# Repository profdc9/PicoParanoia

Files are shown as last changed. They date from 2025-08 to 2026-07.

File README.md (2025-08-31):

# PicoParanoia

This is an update to the ParanoiaBox ( https://www.github.com/profdc9/ParanoiaBox ) which uses a Raspberry Pi Pico rather than a STM32F103CBT6 Blue Pill.  It improves some security aspects of the original, such as having separate SPI ports for the ciphertext and plaintext cards.

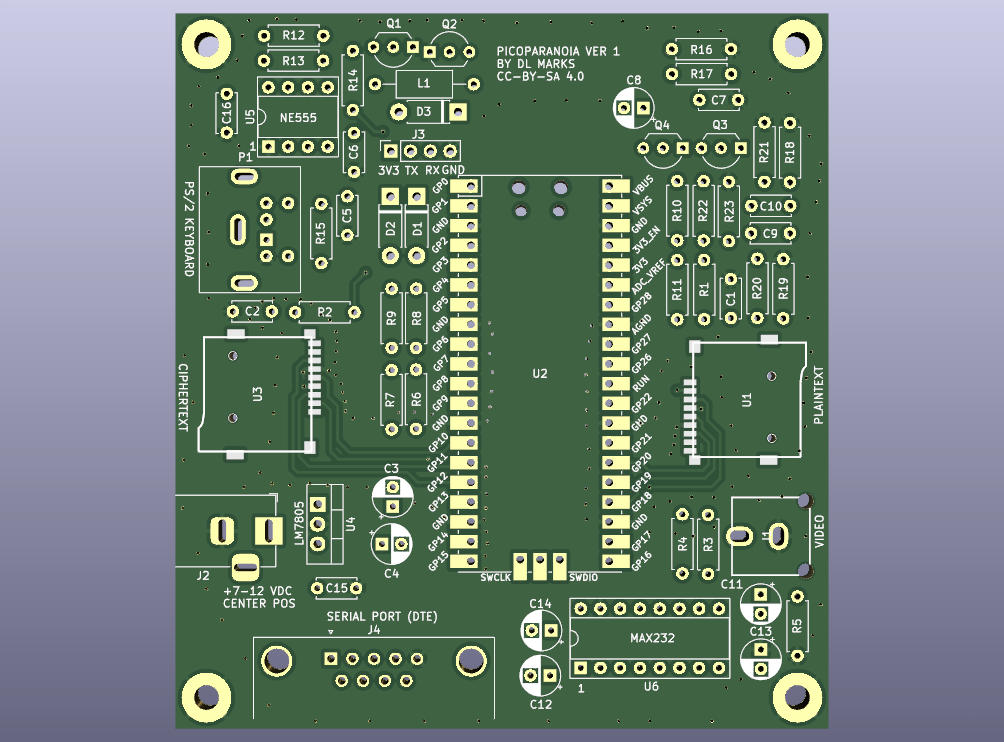
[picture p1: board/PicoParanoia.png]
PCB


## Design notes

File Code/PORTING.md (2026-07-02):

# PicoParanoia — Porting Plan (STM32 ParanoiaBox → RP2040 Pico)

Status: **bring-up step 1 complete** (copy-to-RAM skeleton + vendored crypto
subset building; AES-256-GCM/BLAKE2s self-test ready to flash). Steps 2+ pending.

Porting the ParanoiaBox encryption terminal (`~/projects/ParanoiaBox/code`,
STM32F103CBT6 / stm32duino) to the Raspberry Pi Pico (RP2040), built on the
Pico SDK (vendored at `../pico-sdk`, v2.2.0).

Decision: keep the **Arduino Cryptography Library** (Rhys Weatherley). It is
pure software except for the RNG noise source, which we wire to the RP2040 ADC.

---

## 0. Design principles

This is an encryption device; its credibility rests on the firmware being
**auditable**. Two standing rules shape every decision in this document.

### A. Auditability first

- **Minimize the trusted computing base.** Every dependency is audit surface.
  Vendor and pin all third-party code (Pico SDK, Crypto lib, TinyUSB, FatFs)
  with recorded version + license + provenance; add nothing we can't justify.
- **Isolate the security-critical core** — crypto primitives, key management,
  RNG/entropy, flash key store, and the plaintext/ciphertext data path — into
  small, dependency-light modules reviewable on their own, separate from
  UI / video / USB / SD.
- **Document the trust boundary.** Be explicit about what touches secrets:
  keys & passphrases (`keymanager`, KDF), plaintext (`editor`, plaintext SD
  card, the video display, **and keyboard input — it carries the passphrase**).
  Non-secret: ciphertext, video sync/timing, the NTSC engine internals.
- **Zeroize secrets after use** — wipe key material, derived keys, passphrases,
  and plaintext buffers when done. The STM32 code is inconsistent here; the port
  is the chance to make this systematic.
- **Readable over clever.** Clear names, comments on *why*, modest functions, no
  undefined behavior; match the existing zlib-licensed style.
- **No hidden behavior.** Offline by design — no network, telemetry, or
  auto-update; no code path that isn't on the menu.
- **Constant-time where it matters.** Tag/secret comparisons go through the
  audited Crypto lib; flag any hand-written comparison over secret data.
- **Reproducible builds.** Pinned SDK submodule + toolchain + `copy_to_ram` so an
  auditor can rebuild the exact image and diff it. Document the build.

### B. Reusable, decoupled libraries

- The **NTSC/PAL video driver is a standalone, reusable library** — its own
  directory, its own CMake static-library target, a clean public header, and
  **zero dependency on PicoParanoia** (no `keymanager`/`consoleio`/etc.). It
  knows only about a framebuffer + timing config, so it drops into other
  projects unchanged.
- This *also serves auditability* (principle A): it lifts a large,
  non-security-critical component out of the crypto core's review surface.
- The `consoleio` shim sits **on top of** the video library, bridging it (and
  the keyboard) to the app — app-specific behavior stays out of the library.

---

## 1. Hardware differences (STM32 Blue Pill → RP2040 Pico)

### 1.1 Pin map (RP2040, confirmed 2026-06-30)

| Function | RP2040 GPIO | Notes |
|---|---|---|
| PS/2 DATA | GPIO4 | was `PB4` |
| PS/2 CLK | GPIO5 | was `PB5` |
| Ciphertext SD — SCK | GPIO10 | HW peripheral **spi1** |
| Ciphertext SD — MOSI | GPIO11 | |
| Ciphertext SD — MISO | GPIO12 | |
| Ciphertext SD — CS | GPIO13 | was shared bus + `PB8` CS |
| Plaintext SD — SCK | GPIO18 | HW peripheral **spi0** |
| Plaintext SD — MOSI | GPIO19 | |
| Plaintext SD — MISO | GPIO20 | |
| Plaintext SD — CS | GPIO21 | was shared bus + `PB9` CS |
| Video VSYNC | GPIO16 | NTSC/PAL |
| Video pixel clock | GPIO17 | NTSC/PAL |
| Noise transistor A | GPIO26 | ADC channel 0 |
| Noise transistor B | GPIO27 | ADC channel 1 |
| UART TX | GPIO0 | HW peripheral **uart0** |
| UART RX | GPIO1 | |
| UART CTS | GPIO2 | hardware flow control |
| UART RTS | GPIO3 | hardware flow control |

Exposed serial port (UART) — **not needed for the initial port, recorded for
later use.** GPIO0/1 are the RP2040 `uart0` function pins, with CTS/RTS flow
control on GPIO2/3.

### 1.2 Two SD cards on independent SPI buses (security-critical)

The STM32 version put **both** SD cards on a single SPI bus, distinguished
only by chip-select lines (`PB8` ciphertext, `PB9` plaintext). The Pico
version deliberately puts each card on its **own SPI controller** so that
neither card can electrically observe the other's traffic — preserving the
plaintext/ciphertext air-gap that is the whole point of the device.

- Ciphertext card → RP2040 **spi1** (GPIO10–13)
- Plaintext card → RP2040 **spi0** (GPIO18–21)

**Naming gotcha:** the schematic labels these nets "SPI2" (ciphertext) and
"SPI1" (plaintext), which are *off by one* from the RP2040 peripheral names
(`spi1` and `spi0` respectively). Code and comments must state which numbering
is meant. The FatFs disk-IO glue needs two independent SPI contexts, one bound
to each controller — not one bus with two CS lines.

### 1.3 Hardware RNG: dual simultaneous ADC → single muxed ADC

STM32 `random.cpp` drove `ADC1` and `ADC2` **simultaneously** (register-level
`SQR3`/`CR2`/`SR`/`DR` pokes) to sample two noise transistors at once. The
RP2040 has a **single** ADC multiplexed across channels. The two transistors
on ADC0 (GPIO26) and ADC1 (GPIO27) must be sampled in sequence (switch the
input mux between conversions, or use round-robin mode) and combined. The
output then feeds the Arduino Crypto library's `RNG` whitening.

#### 1.3.1 Low noise amplitude → only the lowest LSBs are random (critical)

The noise source is a **reverse-biased emitter–base junction**, and its noise
amplitude is only **~100 mV**. Against the RP2040's 12-bit ADC over a 3.3 V
reference (**~0.8 mV/LSB**), 100 mV spans only ~125 codes — and the *random*
content lives in just the **lowest few LSBs** of each sample. The upper bits
track the DC bias and slow drift, not entropy. So a raw ADC sample carries far
less real entropy than its bit-width suggests.

**Design mandate (do not skimp on entropy):**

- **Credit conservatively.** Assume only a small handful of bits — treat it as
  **≤1–2 bits of true min-entropy per ADC sample** (or less), never the full
  8/12 bits. Tell the `RNG`/`NoiseSource` credit accounting this low number.
- **Oversample *very* generously.** Gather many times more raw samples than the
  output needs and fold them all through the BLAKE2s/ChaCha whitening pool. For
  any key, nonce, IV, salt, or ECDH scalar, target a large safety margin
  (**≫10×** the credited bits required) so the noise source is **never** the
  limiting factor. When in doubt, gather more.
- **Block until satisfied.** Before generating key material, force a generous
  entropy stir-in and wait until the pool has absorbed well beyond the nominal
  requirement — never produce a key/nonce from a thin pool.
- **Debias / combine.** Prefer the low bits; consider von Neumann debiasing and
  XOR-combining the two independent channels (GPIO26/GPIO27) before crediting.
- **Health check.** Implement a real stuck-source detector (the STM32
  `random_circuit_check()` was an empty stub): if the LSBs go constant the
  junction/biasing has failed, and oversampling a dead source yields nothing —
  fail loudly rather than emit predictable keys.

This is a security-critical, auditable property (§0.A): generosity here is
deliberate and must be obvious in the code and its comments.

#### 1.3.2 RNG construction: direct BLAKE2s extraction (decided)

The conditioner is a **direct hash extractor**: sample the noise generously,
fold it through **BLAKE2s**, and take the digest as the random output — no
long-lived DRBG state. Chosen over an extract-then-DRBG hybrid because our
random demand is small and intermittent (keys, nonces, IVs, salts, ECDH
scalars), and a stateless "hash a big pile of fresh noise" construction is the
easiest thing for an auditor to trust (§0.A).

- **Memory cost is negligible — no need to buffer the oversampled noise.**
  BLAKE2s is incremental, so samples are `update()`-ed into the hash state as
  they're collected and immediately discarded. The only standing memory is the
  BLAKE2s context (~100–200 B) plus a tiny per-sample working buffer — *not* the
  thousands of raw samples. (Even copy-to-RAM's 264 KB would swallow a multi-KB
  buffer easily; we simply don't need one.)
- **One 256-bit extraction covers every secret we generate.** BLAKE2s' 32-byte
  digest ≥ AES-256 key, ECDH25519 scalar, and any nonce/IV. If something ever
  needs >256 bits, run **independent** extractions over fresh noise (or a keyed
  counter expansion), never stretch one digest.
- **Per call:** reset BLAKE2s → stream in ≫(output bits) of credited noise
  (debiased, two channels XOR-combined, §1.3.1), running the stuck-source check
  as samples arrive → `finalize()` → output. Block until the credited input
  margin is met.
- Reminder: extraction makes a **dead source look random** (§1.3.1), so the
  health check during sampling is what actually guarantees the result, not the
  hash.

### 1.4 Internal flash key storage: STM32 flash controller → RP2040 QSPI

STM32 `flashstruct.cpp` programmed the on-die flash via `FLASH_BASE->KEYR`
unlock + page erase, and `keymanager.h` hardcodes `0x0801E000` (STM32 memory
map). The RP2040 has **no internal flash** — code/data live in external QSPI
flash. Key storage must move to the SDK's `hardware/flash.h`
(`flash_range_erase` / `flash_range_program`, 4 KB sectors). The hardcoded
address and the 16-bit half-word write granularity assumptions go away.

Interaction with copy-to-RAM (§1.9): because the firmware runs entirely from
RAM, the usual "flash writes must execute from RAM with IRQs off" hazard is
largely handled by construction — no code is being fetched from the flash we're
erasing. Reserve a dedicated key region at the **top of flash** (outside the
copied program image) for the encrypted key store. Reading keys back is an
XIP-mapped read of that region; that traffic is acceptable because only
**ciphertext** key blobs ever cross the bus (see §1.9).

### 1.5 NTSC/PAL video generation

STM32 used the `TNTSChar` library, which generated composite video by abusing
an SPI peripheral + timers (libmaple). On RP2040 both SPI controllers are spoken
for by the SD cards, so composite video is generated with **PIO + DMA**.
Architecture settled 2026-06-30; this is the largest single new component, but
fully specified below.

**Output DAC — 2-resistor summing into 75 Ω composite.**
GPIO16 (sync) via **560 Ω** and GPIO17 (luma) via **240 Ω** sum into the 75 Ω-
terminated TV input. Measured/computed levels:

| State | GPIO16 | GPIO17 | Composite |
|---|---|---|---|
| Sync tip | 0 V | 0 V | 0 V |
| Black/blanking | 3.3 V | 0 V | ≈0.31 V |
| White | 3.3 V | 3.3 V | ≈1.02 V |

Standard 0 / 0.3 / 1.0 V composite. **Monochrome** — no colorburst, so the pixel
clock is free of the 3.579545 MHz subcarrier constraint.

**Display model.**
- **Text cells only**, 240p **progressive** (non-interlaced, one field repeated).
  NTSC first; PAL later = different line/field counts + sync templates, same
  machinery (keep all timing in one table).
- **25 rows × 8 px = 200 active lines**, identical in both column modes — so the
  GPIO16 sync waveform is **mode-independent in real time**.
- **40-column (320 active px) and 80-column (640 active px)** both supported,
  switchable like `TNTSChar`.
- **1bpp framebuffer** rendered from a font ROM. Glyphs are drawn into the
  framebuffer **only on text change** (in `console_putch`/scroll), never per
  scanline. Sizes: 40-col 8 KB, 80-col 16 KB (×2 if double-buffered) — trivial
  under copy-to-RAM (§1.8).

**PIO scanout engine.**
- **Two SMs in one PIO block sharing one `clkdiv`**, started together
  (`pio_enable_sm_mask_in_sync`): one drives GPIO16 (sync), one drives GPIO17
  (luma), bit-aligned.
- SMs run **free-running for the whole field**; DMA is **ping-pong/chained** so
  the FIFOs never underrun. (Underrun = loss of lockstep = torn sync — this is
  *the* failure mode to design out, hence no per-line SM restarts.) The per-line
  IRQ only swaps buffer pointers.
- The **sync SM** streams a small set of precomputed line templates selected per
  line by a DMA descriptor list: normal-active, blank, pre-equalizing,
  broad/serration, post-equalizing (NTSC field structure).
- The **luma SM** streams a shared "black" buffer around the active framebuffer
  row each line, so porch/blanking is handled by DMA sequencing and the
  framebuffer stays pure picture (no per-line copy).

**40 vs 80 columns.** Keep the PIO clock **fixed at the 80-col pixel rate**
(~12.2 MHz); 80-col = 1 framebuffer bit/clock, 40-col = each bit held 2 clocks
(double-width pixels). Sync templates and clock are untouched between modes —
only the luma SM packing + framebuffer geometry change. (Alternative: halve the
shared `clkdiv` + mode-specific sync templates. Either way a mode switch
re-inits the engine at a field boundary, which is rare.)

**Pixel clock.** 80-col: 640 px / ~52.6 µs ≈ **12.2 MHz**; 40-col ≈ 6.1 MHz.
Choose sysclk + active-pixel count for an integer / low-jitter PIO divider
(monochrome gives freedom here).

**Scrolling.** A text scroll moves pixels, not just chars, but the cost is
negligible — an 80-col scroll `memmove`s ~15 KB (framebuffer minus one char
row), << one line time. Do it during **vertical blanking** (~3.9 ms available)
to avoid tearing, or render to the back framebuffer and swap. Zero-copy upgrade
if ever needed: a per-line pointer table (ring framebuffer) so a scroll rotates
pointers instead of moving pixels.

**Core split.** *(Updated after first light — superseded for the chosen
single-SM path.)* With the single-SM + precomputed static-frame design, scanout
is pure DMA + PIO with **no per-scanline CPU**, so there is **no video engine
loop and core1 is unused**. Glyph blitting happens on **core0** at text-change
time (blit-on-write), not per line. **core1 is free** — most likely future
tenant is the TinyUSB **host** service loop (deferred, off by default); it can
also absorb an offloaded task if core0 ever gets busy. The original "video on
core1" note applied to the two-SM/per-line-composition model, which we did not
take.

Remaining choices are implementation-level only: exact sysclk/divider, the
scroll-tearing mitigation (vblank memmove vs double-buffer), and the 40-col
mechanism (double-width vs `clkdiv` change).

### 1.6 Keyboard input — PS/2 *or* USB host (new requirement)

The Pico version must accept **either a PS/2 keyboard or a USB keyboard**, a
capability the STM32 version did not have.

- **PS/2:** was the `PS2Keyboard` lib bit-banging `PB4`/`PB5`; same protocol,
  new pins (GPIO4 data, GPIO5 clk). RP2040 PIO program or IRQ bit-bang. Low risk.
- **USB host:** the RP2040 acts as a **USB host** and reads a USB HID boot
  keyboard via TinyUSB host mode. Both sources feed a single key event queue
  that `consoleio` drains, so the rest of the system is source-agnostic.

### 1.7 USB role: device (debug) → host (keyboard) — and what it costs stdio

The RP2040 has **one native USB controller**, which is *either* device *or*
host — not both at once on that port. This drives a deliberate two-phase plan:

- **Bring-up phase:** native USB in **device** mode = USB-CDC serial, used as
  the debug `stdio` console (printf, crypto self-tests, etc.).
- **Target phase:** native USB switches to **host** mode to drive the USB
  keyboard. At that point **USB-CDC stdio is gone** — any persistent debug
  console must move to **`uart0` (GPIO0/1)**, or be compiled out entirely for
  the shipping build.

Implication: treat USB-CDC stdio as **temporary scaffolding**. Keep all debug
output behind a thin logging shim with a build-time backend switch
(USB-CDC ↔ `uart0` ↔ none) so flipping the USB role doesn't ripple through the
code. (A second USB port via Pico-PIO-USB — host on PIO pins while native stays
device — is a possible future option but is **not** assumed here; the board
allocates no pins for it.)

**USB is off by default (least privilege / auditability, §0.A).** Some users
will not trust the USB stack on an encryption device, so USB must be **entirely
compile-time optional and inert unless explicitly enabled**:

- `PICOPARANOIA_ENABLE_USB_HOST` (default **OFF**) — compiles out the TinyUSB
  host + HID-keyboard driver. With it off, the keyboard is PS/2-only and no USB
  code is linked at all.
- `PICOPARANOIA_ENABLE_USB_STDIO` (default **OFF**) — USB-CDC debug console is
  opt-in even during bring-up; a developer turns it on deliberately. Default
  debug target is `uart0` (or none).
- A build with both off links **no USB code**, and the native USB peripheral is
  left uninitialized/inert. Each flag is independent so "USB keyboard, no debug
  CDC" and "CDC debug, PS/2 keyboard" are both valid configs (and the two CDC vs
  host modes remain mutually exclusive per the controller limit above).

This keeps the default firmware's attack/audit surface minimal: no USB unless
the operator chose it.

### 1.8 Execution entirely from RAM (copy-to-RAM) — flash-bus hardening

**Requirement:** the whole firmware image is copied from flash into RAM at
startup and executes from **SRAM**, so that no instruction fetches go out over
the external QSPI flash lines at runtime. Default RP2040 operation is XIP
(execute-in-place), where every cache-missed fetch is visible on the flash bus;
an attacker probing those lines could infer secret-dependent control flow and
data accesses. Running from RAM removes that side channel.

- **Mechanism:** the Pico SDK provides this out of the box —
  `pico_set_binary_type(picoparanoia copy_to_ram)` selects the copy-to-RAM
  linker layout; boot stage 2 copies the image to SRAM and jumps to it. No
  custom bootloader needed.
- **RAM budget (hard constraint):** everything — code, rodata, data, bss,
  stack, heap, **plus** the text-cell video buffer, FatFs/file buffers, USB-host
  buffers, and crypto working state — must fit in the RP2040's **264 KB SRAM**.
  This firmware is small, but watch the file-encryption buffers and keep an eye
  on the map file as modules land. Treat RAM headroom as a tracked budget.
- **Flash stays available for the encrypted key store only.** After the boot
  copy, the flash is otherwise idle. The only runtime bus traffic to flash is
  reading/writing the **encrypted** key region (§1.4) — and because those blobs
  are ciphertext, observing them on the bus leaks nothing useful.
- **Boot copy is not a secret-bearing operation:** the one-time bulk copy of the
  (non-secret) program image happens before any key is decrypted, so the
  unavoidable flash traffic at boot carries no secrets.
- Algorithmic constant-time behavior (execution-*time* side channels) is a
  separate concern, handled in the crypto library, not by this RAM decision.

> Possible hardening to evaluate later: actively quiesce/disable the XIP cache
> and flash between key accesses so the bus is fully idle except during explicit
> encrypted-key reads/writes.

### 1.9 Toolchain / framework

stm32duino Arduino core → bare-metal Pico SDK (CMake, `arm-none-eabi`). No
`Arduino.h`, `Serial`, libmaple, or stm32duino `SPI`/`RNG` glue. `printf`
routes through the logging shim (§1.7). Crypto lib must be compiled as plain
C++ against the SDK rather than the Arduino build. USB stack: **TinyUSB**
(bundled with the SDK) in device mode early, host mode later. Binary type:
**copy-to-RAM** (§1.8).

---

## 2. Module port strategy

Legend: **Reuse** = compiles essentially unchanged · **Shim** = keep the
module's API/logic, swap the platform calls underneath · **Rewrite** = replace
the implementation · **New** = no STM32 counterpart.

| Module (old) | Disposition | Work |
|---|---|---|
| `mini-printf.*` | **Reuse** | Pure C string formatting. |
| `debugmsg.*` | **Shim** | Route through the logging shim (§1.7): `uart0` by default, USB-CDC only if `PICOPARANOIA_ENABLE_USB_STDIO` is set, or none. Not `Serial`. |
| `cryptotool.*` | **Reuse** | AES/GCM/BLAKE2s via Crypto lib, base64, CRC16, KDF — all software. Only `heap_stack_distance()` (uses `sbrk`/frame address) needs an SDK-friendly version or removal. |
| Crypto library | **Reuse (recompile, pinned subset)** | Vendor `libraries/Crypto/` at commit `37a76b8` (§2.3) — the GCM/AES256/CTR/BLAKE2s/Curve25519 subset, plus ChaCha/ChaChaPoly/Poly1305 added later (§2.1 step 7a) when the active AEAD cipher was swapped to ChaCha20-Poly1305; GCM/AES256 stay vendored for their KAT. Compile as plain C++ against the SDK. **Drop `RNGClass`/`NoiseSource`/Arduino glue entirely** — direct BLAKE2s extraction (§1.3.2) replaces the DRBG, so that Arduino-coupled code never enters the build (the standalone `ChaCha` class is vendored, but not `RNGClass`'s own use of it). |
| `editor.c` | **Reuse** | Talks only to the `consoleio` API; works once console is up. |
| `keymanager.*` | **Shim** | Logic is portable. Replace the flash-storage backing (see `flashstruct`) and the hardcoded `0x0801E000` address with an RP2040 QSPI region. |
| `fileenc.*` | **Reuse** | Pure logic over `keymanager` + `fileop` + `cryptotool`. |
| `fileop.*` | **Shim** | FatFs calls stay; the disk-IO layer underneath becomes two independent SPI/SD contexts (see below). `fs0`=ciphertext, `fs1`=plaintext. |
| FatFs | **Update + new glue** | Move to **R0.16** (§2.3), replacing the old STM32-glued `ElmChanFatFs`. Portable `source/` + our own `diskio.c` for the two SPI buses (`sdmm.c` sample as reference); `FF_VOLUMES = 2`. |
| `consoleio.*` | **Shim** | Keep the entire `console_*` API (everything above depends on it). Swap the backends: output → NTSC text driver; input → a key event queue fed by **both** PS/2 and USB-host drivers. ANSI handling can stay. |
| `random.*` | **Rewrite** | Single muxed RP2040 ADC sampling ch0/ch1 in sequence → **direct BLAKE2s extraction** (§1.3.2), streamed incrementally (no raw buffer). Apply §1.3.1: conservative per-sample credit, **very generous oversampling**, block-until-satisfied, stuck-source health check. Drops the Crypto-lib ChaCha `RNG`/DRBG in favor of the stateless extractor. |
| `SimpleTransistorNoiseSource.*` | **Drop** | No longer needed — the `NoiseSource` abstraction existed only to feed the Crypto-lib DRBG. Direct BLAKE2s extraction (§1.3.2) folds ADC capture + debias + credit directly into `random.*`. |
| `flashstruct.*` | **Rewrite** | STM32 flash controller → `hardware/flash.h` (`flash_range_erase`/`program`, 4 KB sectors). Dedicated key region at top of flash, outside the copied image (§1.4/§1.8). |
| `TNTSChar` / `TNTSCAnsi` | **New** | **Standalone `pico_ntsc` library** (§0.B, §2.2). *As built:* single PIO SM (2 bits/sample sync+luma) + self-reloading DMA over a precomputed static frame — autonomous scanout, no per-line CPU, **core1 unused**; blitter writes glyphs into the frame on core0 at text-change time. 40/80-col, font toggle. Zero app coupling. `TNTSCAnsi`'s ANSI/cursor logic moves up into `consoleio`; reuse font data if usable. |
| `PS2Keyboard` | **New** | RP2040 PS/2 driver (PIO or IRQ bit-bang) on GPIO4/5, pushing into the shared key event queue. |
| — | **New (opt-in)** | **USB-host HID keyboard** driver (TinyUSB host) feeding the same key event queue. Compiled in **only** when `PICOPARANOIA_ENABLE_USB_HOST` is set (default **off**, §1.7); otherwise no USB code links and the keyboard is PS/2-only. |
| — | **New** | **Logging shim** (§1.7): build-time backend switch `uart0` (default) ↔ USB-CDC (`PICOPARANOIA_ENABLE_USB_STDIO`, default off) ↔ none. |
| `ParanoiaBox.ino` | **Rewrite** | Becomes `main.c`: SDK init, peripheral bring-up, then the existing menu/dispatch loop. |
| — | **New** | Board pin-definitions header (single source of truth for the §1.1 map). |
| — | **Build config** | `pico_set_binary_type(picoparanoia copy_to_ram)` so the image runs entirely from SRAM (§1.8); reserve a flash key region in the linker/flash layout. USB feature flags `PICOPARANOIA_ENABLE_USB_HOST` / `PICOPARANOIA_ENABLE_USB_STDIO` both default **off** (§1.7). |

### 2.1 Build / bring-up order (bottom-up, de-risk video early)

1. **Skeleton + crypto (copy-to-RAM from the start):** ✅ **DONE.** SDK project
   builds with `copy_to_ram` (verified: `.text` VMA in SRAM); vendored Crypto
   subset in `third_party/crypto` (GCM/AES256/CTR/BLAKE2s + deps, Curve25519
   deferred to step 5); `src/main.cpp` self-tests AES-256-GCM + BLAKE2s against
   known-answer vectors. Console is **USB-CDC for now** (temporary bring-up
   convenience — the §1.7 default of uart0 + USB-off is restored before USB-host
   support lands, which is itself deferred). RAM: ~70 KB used, ~194 KB free.
   *Remaining:* run on hardware to see the PASS/FAIL print; vendor FatFs R0.16
   into `third_party/fatfs` (not needed until step 6).
2. **Video out (highest risk):** NTSC text-cell driver on GPIO16/17. Get a
   character grid on a TV. Prototype this early — it gates the UI.
   - *In progress:* `pico_ntsc/` library scaffolded (standalone, §0.B); two
     public-domain readability-tuned font tables built — `unscii8` (regular,
     for 80-col) and `unscii8_thin` (40-col), with 0x00–0x1F spliced from the
     old `raster88_font`. Single-byte cell model kept (glyph `cell&0x7F`, bit7 =
     reverse); global runtime-toggleable font choice. Font is a 1px-vs-2px stem
     readability tradeoff vs the ~3–5 MHz TV luma bandwidth.
   - *First light CONFIRMED on hardware (2026-06-30):* stable, fully locked
     raster — 19 vertical bars visible (≈20 minus overscan), perfectly
     stationary. Validates the whole video chain (PIO 2-bit sync+luma,
     self-reloading DMA, 240p timing, resistor DAC). Engine details: sysclk
     126 MHz,
     12.6 MHz sample clock, 800 samples/line = 15750 Hz, 262 lines = 60.1 Hz.
     One PIO SM emits 2 bits/sample (sync+luma) fed by a self-reloading DMA loop
     over a precomputed frame (eq/serration/blank/active templates) — static,
     no CPU/core1. Pattern: 16px vertical bars + white border. `pico_ntsc.c`,
     `ntsc.pio`. *(Single-SM 2-bit approach for robust first-light; may move to
     the 2-SM model from §1.5 for the text path once sync lock is confirmed.)*
   - *Text path DONE — confirmed rock-steady on hardware (2026-06-30):* glyph
     blitter writes into the active frame (blit-on-write, core0); public API
     `pico_ntsc_init`/`put_cell`/`put_text`/`clear`/`set_mode`/`set_font`/
     `set_cursor`. Cursor owned by the library, XOR-rendered from a repeating
     timer. 80- and 40-col (40 = double-width). Per-mode default font: unscii-8
     regular @ 80, unscii-8 thin @ 40.
   - *Horizontal timing corrected to match the STM32 generator (this fixed the
     overscan):* the first-light 12.6 MHz pixel clock made the active 80% of the
     line (overscanned off the edges) and crowded the sync. Now **sysclk 126 MHz,
     clkdiv 7 → sample clock exactly 18 MHz**; **1144 samples/line = 4.5 MHz/286 =
     15734.27 Hz (exact NTSC)**, 262 lines = 60.05 Hz. Active is a **narrow ~35.6
     µs (56% of line, 640 px)** with a **fat ~9.8 µs back porch**, sitting inside
     overscan. PAL is the same clock with 1152 samples/line → exactly 15625 Hz.
     Because 1144 isn't ÷16, the framebuffer is indexed by absolute sample (the
     frame total *is* word-aligned). Frame buffer ~73 KB. Vertical sync = 3
     progressive sync-low lines (`build_vsync`), the STM32 scheme.
   - *Console DONE — confirmed on hardware (2026-06-30):* the old **TNTSCAnsi**
     VT100 emulator is reused verbatim as a standalone text-buffer emulator, with
     a single optional per-cell **hook macro** (`VS_PUT` → `TNTSCANSI_CELL_CHANGED`,
     no-op by default; PicoParanoia's `tntscansi_hook.h` maps it to
     `pico_ntsc_put_cell`). So VS_PUT updates the char buffer *and* blits the one
     changed cell — no diff/re-render. `consoleio` ported nearly verbatim on top;
     input from PS/2 with a USB-serial fallback. `src/{consoleio,TNTSCAnsi}`,
     `pico_ps2kbd/`.
3. **Keyboard in — DONE (2026-06-30):** `ps2_kbd` ports the PS/2 state machine to
   an RP2040 falling-edge GPIO IRQ (clock GPIO5, data GPIO4) → ASCII FIFO →
   `console_getch`. Confirmed on hardware (with a 5V→3.3V shifter). USB-serial
   input also works for keyboard-less testing. Later split into its own
   standalone `pico_ps2kbd` library (own CMake target), matching `pico_ntsc`
   (housekeeping for the eventual USB-host keyboard work below). **USB-host**
   keyboard deferred to
   step 9.
4. **RNG — DONE (2026-07-01):** direct BLAKE2s extraction from ADC noise on
   GPIO26/27 (`random.cpp`), not the STM32's ChaCha-CSPRNG-via-NoiseSource
   path. Heavy oversampling (512 raw bytes -> 32-byte block) plus continuous
   SP 800-90B RCT/APT health tests and a peak-to-peak stuck-source check;
   confirmed on hardware, including a real fault injection (pulling the
   avalanche supply's 555 mid-run) correctly tripping the health check.
   Later blended with `pico_ps2kbd` keystroke-timing jitter as defense in
   depth (2026-07-01).
5. **Flash key store — DONE (2026-07-01):** `flashstruct` rewritten for
   RP2040 XIP flash (erase/program, not the STM32 register-level driver);
   `keymanager` persists the encrypted key table there (AES-256-GCM at the
   time, ChaCha20-Poly1305 as of the cipher swap below). Curve25519
   `dh1()`/`dh2()` draw entropy through a small `RNGClass::rand()` shim
   (`arduino_rng_glue.cpp`) rather than the Arduino RNG/ChaCha stack, so the
   vendored crypto library stays byte-for-byte unmodified. Confirmed on
   hardware: keys persist across power-cycle and unlock with the passphrase.
6. **SD cards — DONE (2026-07-01):** dual-bus FatFs glue (spi1=ciphertext,
   spi0=plaintext, `sd_spi.c`) → `fileop` mounts both volumes. Confirmed on
   hardware at the 12.5 MHz SD SPI-mode default.
7. **File crypto — DONE (2026-07-02):** `fileenc` end-to-end (encrypt on
   plaintext card → ciphertext card and back), both the symmetric/passphrase
   and ECDH shared-secret paths. Confirmed on hardware: both key types
   round-trip correctly.
7a. **Symmetric cipher swap: AES-256-GCM → ChaCha20-Poly1305 — DONE
   (2026-07-02):** AES-256-GCM was the original choice from the STM32-era
   code; ChaCha20-Poly1305 is the better default now and was already in the
   vendored Crypto library, sharing the exact same 256-bit key / 96-bit IV /
   128-bit tag sizes. Done in three steps: (1) generalized every AES_*/aes_*
   name that named a *role* rather than the algorithm to SYMMETRIC_* (
   `cryptotool.h`), so `keymanager`/`fileenc` never spell out which cipher is
   in use — verified as a pure rename with a byte-for-byte identical
   recompile (two isolated worktrees, sha256-matched `.bin`/`.uf2`, only the
   "AES"→"SYMM" key-type label differed in a controlled re-diff); (2)
   vendored `ChaCha.[ch]`/`ChaChaPoly.[ch]`/`Poly1305.[ch]` (§2.3) and
   KAT-validated on hardware before wiring anything in (RFC 8439 §2.8.2
   vector); (3) cut over `symmetric_memcrypt()` and `fileenc`'s streaming
   cipher to `ChaChaPoly`, bumping `FILEENC_EXPORT_VERSION`. Confirmed on
   hardware: 5/5 KAT self-test, fresh key generation, full encrypt/decrypt
   round-trip. This is a clean cutover, not a migration — pre-existing
   AES-256-GCM key stores/files are rejected (`"Header Tag is invalid"`, the
   AEAD tag gate fires before the version check and is unconditional on a
   cipher mismatch); the flash key store correctly falls back to its
   `000DESTRUCT0` reset flow. AES-256-GCM stays vendored, still exercised by
   its own KAT, but is no longer the active cipher. Gotcha found and
   documented (`third_party/crypto/PROVENANCE.md`): `ChaChaPoly::ivSize()`
   returns 8 (the original 64-bit-nonce variant), not the RFC 8439 96-bit
   nonce everything else here assumes — both call sites pass an explicit,
   named `SYMMETRIC_IV_WIRE_LEN` (12) rather than trusting `ivSize()`.
8. **Integrate — DONE (2026-07-02):** the main menu loop is ported and
   everything above is wired together and hardware-tested as a whole. Default
   shipping config restored: `PICOPARANOIA_ENABLE_USB_STDIO` (default **OFF**)
   selects `uart0` (GPIO0/1) as the debug console by default, with USB-CDC
   available only as an explicit opt-in build flag for bring-up debugging.
   Confirmed no USB/TinyUSB code links when off (0 `tud_`/`tusb_` symbols),
   `uart0`'s stdio driver links correctly when it's the target, and the image
   shrinks ~13.4 KB with USB-CDC out of the build. The device is fully
   functional with no USB code linked in this default config.
9. **USB-host keyboard (opt-in feature) — DONE (2026-07-02):**
   `pico_usbhostkbd`, a standalone library matching `pico_ps2kbd`'s shape
   (`init`/`getkey`, plus the same keystroke-timing entropy accumulator
   blended into `random.cpp`), built only when `PICOPARANOIA_ENABLE_USB_HOST`
   is on (default off; mutually exclusive with `PICOPARANOIA_ENABLE_USB_STDIO`
   at CMake configure time -- RP2040 has one native USB controller). TinyUSB
   host + the HID host class driver run entirely on **core1**
   (`tuh_init()`/`tuh_task()` loop -- the documented tenant for the otherwise-
   idle core, §1.5), decoding boot-protocol keyboard reports via TinyUSB's own
   `HID_KEYCODE_TO_ASCII` table (not hand-transcribed) and pushing into a FIFO
   `consoleio` drains alongside PS/2's, so both sources can be live at once
   (separate GPIOs vs. USB, no conflict) -- the "single key event queue" this
   section originally called for, drained from two FIFOs in priority order
   rather than merged upstream into one. `tusb_config.h` is deliberately
   minimal: one keyboard, no hub/MSC/CDC/vendor class, matching §0.A's
   TCB-minimization principle.

   First hardware attempt found the keyboard undetected. Root cause was a
   real hardware gap, not firmware: the board (a stock Pico module on the
   custom PCB, confirmed from the schematic -- `RPi_Pico:RPi_Pico_SMD_TH`)
   has `VBUS` wired only as a power *input* (pin 40, `power_in`), with no
   net tying it to `VSYS` or any other 5V source -- a stock Pico's USB port
   can never *source* power to a downstream device, only receive it, so a
   plain USB-OTG adapter cannot power a keyboard through it. Diagnosed by
   reading the schematic directly rather than guessing, then localized with
   four connection-stage counters added to `pico_usbhostkbd`
   (`core1_alive`/`dev_mounts`/`hid_mounts`/`reports`, menu **U**, refreshing
   live) once external 5V got the keyboard powered -- all four counters
   climbed cleanly (`core1_alive` in the tens of millions, `dev_mounts=1`,
   `hid_mounts=2`, `reports` and the matching `entropy_cnt` both climbing
   with each keystroke), and typed characters -- letters, backspace, enter,
   arrows -- appear correctly at the normal console, confirmed on hardware.
   A permanent VBUS power-injection circuit (diode or load-switch from VSYS,
   not a direct short -- backfeed risk if the same port is ever used as a
   device port) is future board-revision work, not required for this to work
   with external power.

### 2.2 Repo / library layout

Structured to keep the standalone video library (§0.B) and the security core
(§0.A) cleanly separated:

```
Code/
  pico_ntsc/          standalone, reusable video library — own CMake target
    pico_ntsc.h         clean public API: framebuffer + timing only, no app deps
    ...                 PIO programs, sync templates, glyph blitter
  pico_ps2kbd/        standalone, reusable PS/2 keyboard library — own CMake target
    pico_ps2kbd.h       clean public API: init + getkey, no app deps
    pico_ps2kbd.c       GPIO edge IRQ, scancode decode, FIFO
  src/                PicoParanoia firmware
    main.c
    consoleio.*         bridges pico_ntsc + pico_ps2kbd to the app (not in either lib)
    crypto core:        cryptotool, keymanager, fileenc, random, flashstruct
    drivers:            usb_host_kbd (planned), sd_spi glue, logging shim
  third_party/        vendored + pinned, each with version/license/provenance
    crypto/             Arduino Cryptography Library (recompiled, no Arduino glue)
    fatfs/              ElmChan FatFs (portable core + our RP2040 disk-IO glue)
  CMakeLists.txt      copy_to_ram binary type; links pico_ntsc + pico_ps2kbd + third_party
```

The crypto core has no dependency on `pico_ntsc` or the USB/SD stacks beyond the
defined data-path interfaces, so it can be audited in isolation.

### 2.3 Vendored dependencies (pinned, with provenance)

Per §0.A, every third-party component is vendored, pinned, and recorded:

| Dependency | Version / pin | License | Source | TCB role |
|---|---|---|---|---|
| Pico SDK | 2.2.0 (submodule) | BSD-3-Clause | github.com/raspberrypi/pico-sdk | platform |
| FatFs | **R0.16** (2025-07-22) | 1-clause BSD-style (ChaN) | elm-chan.org/fs/ff — staged in `Code/archives/ff16.zip` | filesystem (unavoidable) |
| Arduino Cryptography Library | **commit `37a76b8`** (2024-05-27) | MIT (Southern Storm / R. Weatherley) | github.com/rweather/arduinolibs | **security core** |
| TinyUSB | bundled with Pico SDK | MIT | — | optional (USB, §1.7) |

Notes:
- **FatFs R0.16** replaces the old `ElmChanFatFs` (the STM32 version shipped an
  R0.1x with STM32-specific glue). Vendor `source/` (`ff.c`, `ffunicode.c`,
  `ffsystem.c`, `ff.h`, `ffconf.h`, `diskio.h`) and write our own `diskio.c`
  for the two SPI buses. `ffsample/generic/sdmm.c` (from `ffsample.zip`) is a
  clean SD/MMC-over-SPI reference for that glue. Set `FF_VOLUMES = 2`.
- **Crypto lib — vendor only the needed subset** (minimize TCB): the project
  uses **GCM, AES256, CTR, BLAKE2s, Curve25519** plus their dependencies
  (`Cipher`/`BlockCipher`/`AuthenticatedCipher`, `AESCommon`, `GF128`/`GHASH`,
  `BigNumberUtil`, `Crypto.*`). Take only `libraries/Crypto/`, not the rest of
  the arduinolibs repo; drop `AESEsp32`, `examples/`, and Arduino-only pieces.
- **`RNGClass`/`ChaCha`/`NoiseSource` are excluded** (not just shimmed): the
  decision to use direct BLAKE2s extraction (§1.3.2) means the lib's DRBG — the
  only Arduino-coupled part (EEPROM/`millis`) and the only consumer of `ChaCha`
  here — never enters the build. One fewer primitive and zero Arduino RNG glue
  in the TCB.

## 3. Open questions

- ~~Composite-video signal scheme on GPIO16/17~~ — **resolved (§1.5):** 2-resistor
  DAC (560 Ω sync / 240 Ω luma), monochrome, 240p progressive, two free-running
  lockstep PIO SMs + ping-pong DMA, 1bpp framebuffer, 40/80-col.
- Whether the existing `TNTSCharfont` glyph data is reusable as-is for the new
  video driver (8×8 cells assumed; confirm dimensions/encoding).
- SD card supply voltage / level shifting on the two buses (hardware) and max
  workable SPI clock per bus.
- ~~Console stdio target~~ — **resolved (§1.7):** USB-CDC for bring-up, then it
  goes away when native USB becomes a keyboard host; persistent debug moves to
  `uart0` or is compiled out.
- USB-host scope: boot-protocol HID keyboard only, or also hubs / NKRO report
  protocol? (Boot keyboard is the simple, sufficient default.)
- Behavior when both a PS/2 and a USB keyboard are attached — just merge both
  into the queue, or pick one?
- RAM headroom under copy-to-RAM (§1.8): does the full build (code + video
  buffer + file buffers + USB host + crypto) fit comfortably in 264 KB, and how
  big do the file-encryption buffers need to be?
- Whether to actively quiesce/disable XIP + flash between encrypted-key accesses
  for maximum bus idleness (§1.8 hardening note).
- _(more as they arise)_

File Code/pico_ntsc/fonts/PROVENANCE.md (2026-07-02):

# Vendored font data (pico_ntsc)

`pico_ntsc_fonts.c` is **generated**, not hand-written. Two 128×8 8×8 tables,
MSB = leftmost pixel. Single-byte cell model: glyph index is `cell & 0x7F`;
bit 7 of the cell selects reverse video (applied by the blitter, not stored in
the glyph). All sources are **public domain**.

## Codepoints 0x20–0x7F — Unscii

- **Source:** Unscii by Viznut — http://viznut.fi/unscii/
- **Files:** `unscii-8.hex` (regular) and `unscii-8-thin.hex` (thin), 8×8 variant.
- **License:** public domain.
- Two weights are kept for readability tuning (PORTING.md §1.5): the regular
  weight has ~2px stems and stays legible at 80 columns where TV luma bandwidth
  attenuates 1px detail; the thin weight is crisper at 40 columns / on
  higher-bandwidth displays. Selection is global (whole screen), runtime-toggleable.

## Codepoints 0x00–0x1F — raster88_font

- **Source:** `raster88_font` from the original ParanoiaBox
  (`libraries/TNTSChar/TNTSCharfont.c`), header note: "These fonts are in the
  public domain."
- These CP437-style control-range UI symbols (card suits, arrows, inverse
  boxes, …) are spliced in because Unscii leaves that range blank. Bit order
  already matches Unscii (MSB = leftmost), verified against the ►/◄ glyphs.

## Regeneration

Tables were produced by parsing the upstream `.hex` files (rows 0–7) for
0x20–0x7F and the first 32 `raster88_font` entries for 0x00–0x1F. If the set
ever changes, regenerate rather than editing `pico_ntsc_fonts.c` by hand.

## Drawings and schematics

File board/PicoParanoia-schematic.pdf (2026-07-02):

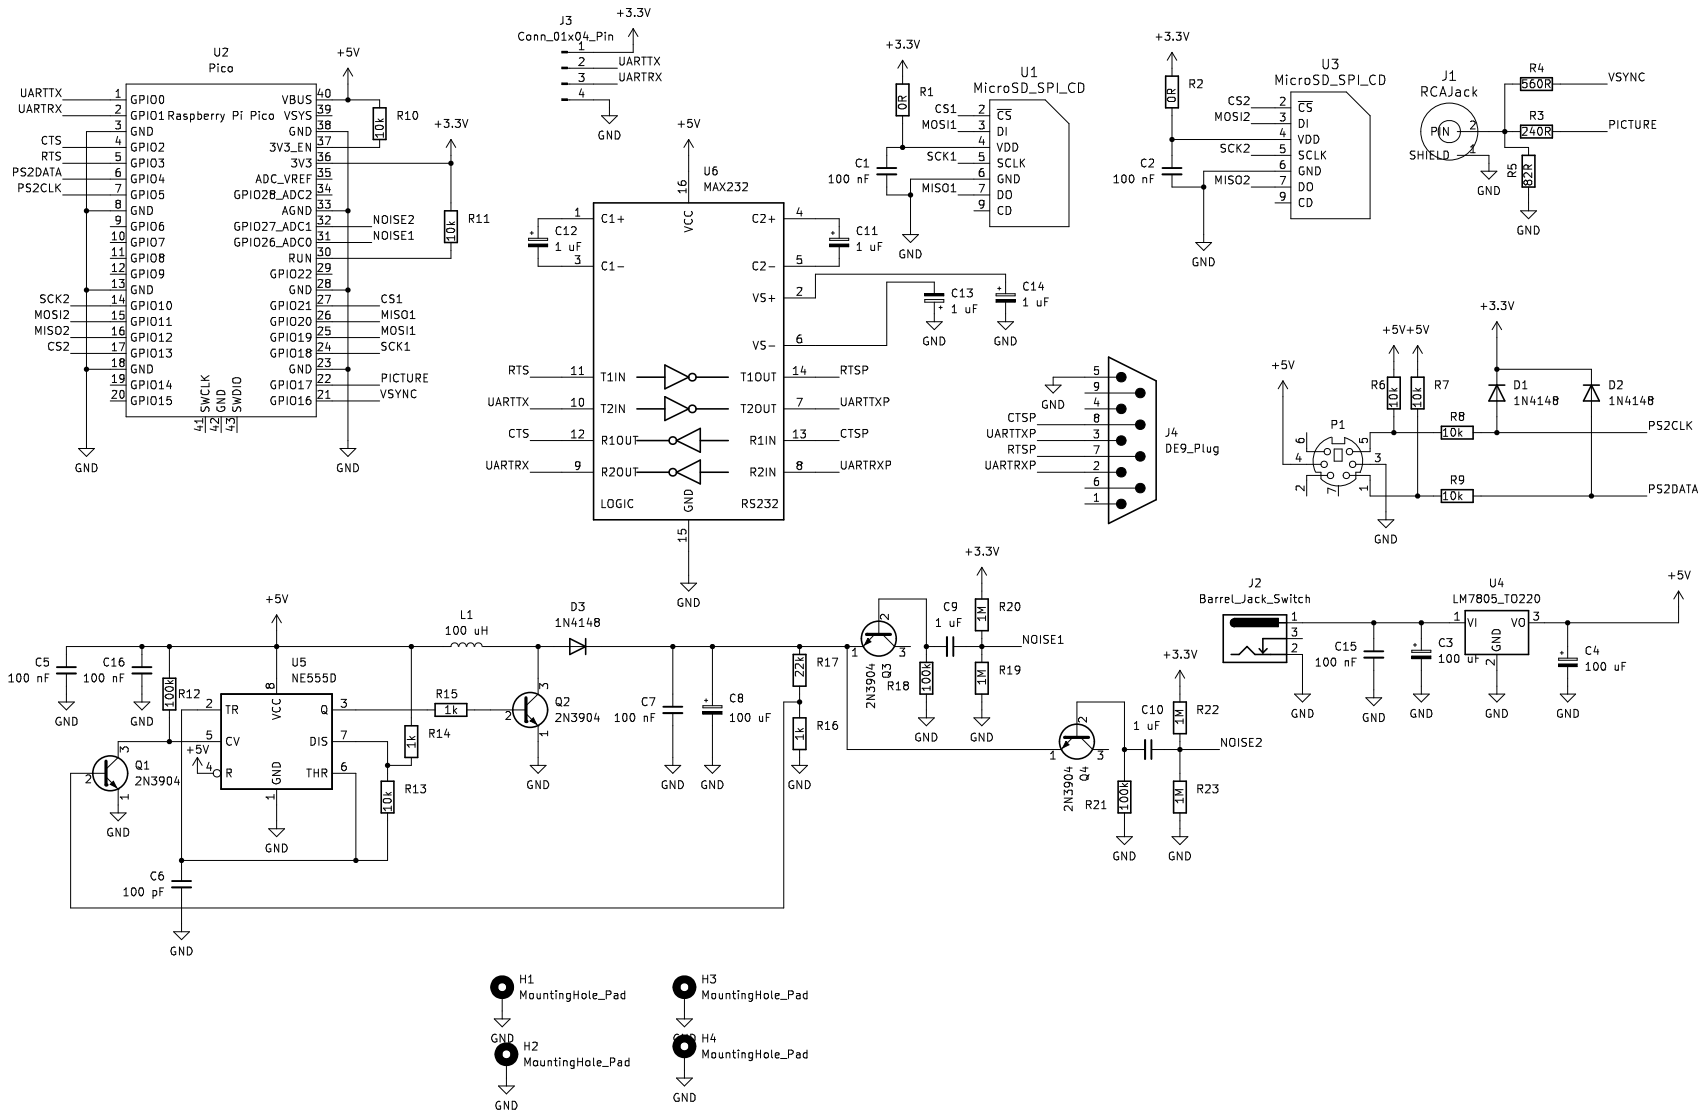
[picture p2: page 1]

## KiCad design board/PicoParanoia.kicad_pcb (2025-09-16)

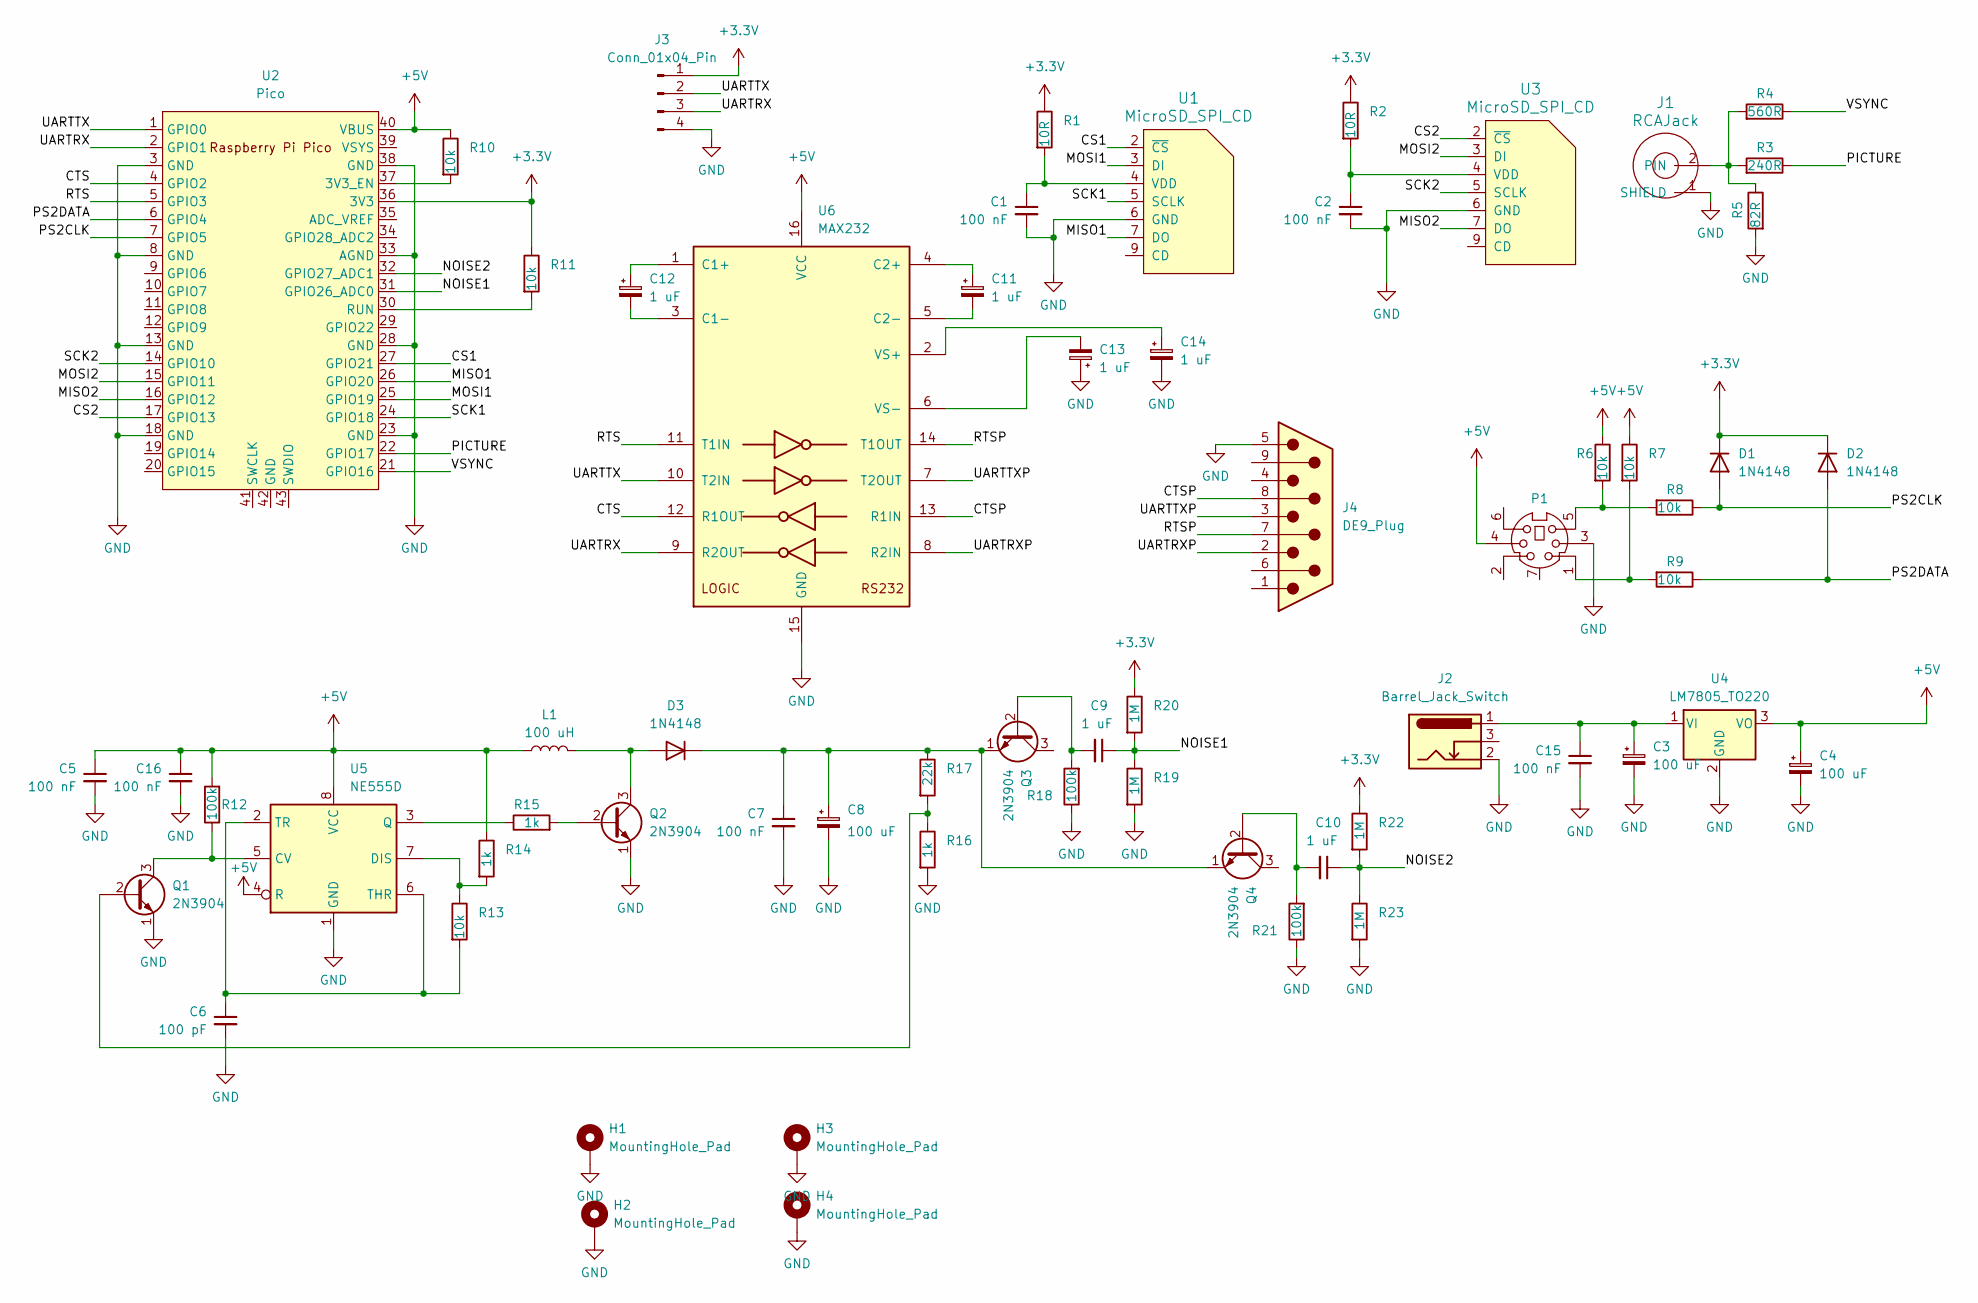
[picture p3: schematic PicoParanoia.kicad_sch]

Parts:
C1, C2, C5, C7, C15, C16: 100 nF; C_Disc_D5.0mm_W2.5mm_P5.00mm
C3, C4, C8: 100 uF; CP_Radial_D5.0mm_P2.50mm
C6: 100 pF; C_Disc_D5.0mm_W2.5mm_P5.00mm
C9, C10: 1 uF; C_Disc_D5.0mm_W2.5mm_P5.00mm
C11, C12, C13, C14: 1 uF; CP_Radial_D5.0mm_P2.50mm
D1, D2, D3: 1N4148; D_DO-41_SOD81_P7.62mm_Horizontal
H1, H2, H3, H4: MountingHole_Pad; MountingHole_3.2mm_M3_Pad
J1: RCAJack; RCAConnectorCommon
J2: Barrel_Jack_Switch; BarrelJack_Horizontal
J3: Conn_01x04_Pin; PinSocket_1x04_P2.54mm_Vertical
J4: DE9_Plug; DSUB-9_Male_Horizontal_P2.77x2.84mm_EdgePinOffset4.94mm_Hou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
L1: 100 uH; L_Axial_L7.0mm_D3.3mm_P12.70mm_Horizontal_Fastron_MICC
P1: Mini-DIN_6pins_ver4; Connector_Mini-DIN_Female_6Pin_2rows
Q1, Q2, Q3, Q4: 2N3904; TO-92_Inline_Wide
R1, R2: 10R; R_Axial_DIN0207_L6.3mm_D2.5mm_P7.62mm_Horizontal
R3: 240R; R_Axial_DIN0207_L6.3mm_D2.5mm_P7.62mm_Horizontal
R4: 560R; R_Axial_DIN0207_L6.3mm_D2.5mm_P7.62mm_Horizontal
R5: 82R; R_Axial_DIN0207_L6.3mm_D2.5mm_P7.62mm_Horizontal
R6, R7, R8, R9, R10, R11, R13: 10k; R_Axial_DIN0207_L6.3mm_D2.5mm_P7.62mm_Horizontal
R12, R18, R21: 100k; R_Axial_DIN0207_L6.3mm_D2.5mm_P7.62mm_Horizontal
R14, R15, R16: 1k; R_Axial_DIN0207_L6.3mm_D2.5mm_P7.62mm_Horizontal
R17: 22k; R_Axial_DIN0207_L6.3mm_D2.5mm_P7.62mm_Horizontal
R19, R20, R22, R23: 1M; R_Axial_DIN0207_L6.3mm_D2.5mm_P7.62mm_Horizontal
U1, U3: MicroSD_SPI_CD; GCT-MEM2055-00-190-01-A
U2: Pico; RPi_Pico_SMD_TH
U4: LM7805_TO220; TO-220-3_Vertical
U5: NE555D; DIP-8_W7.62mm_Socket
U6: MAX232; DIP-16_W7.62mm_Socket

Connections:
+3.3V: D1.1 (K), D2.1 (K), J3.1, R1.1, R2.1, R11.1, R20.1, R22.1, U2.36 (3V3)
+5V: C4.1, C5.1, C16.1, L1.1, P1.4, R6.1, R7.1, R10.1, R12.2, R14.1, U2.40 (VBUS), U4.3 (VO), U5.4 (R), U5.8 (VCC), U6.16 (VCC)
/CS1: U1.2 (~CS), U2.27 (GPIO21)
/CS2: U2.17 (GPIO13), U3.2 (~CS)
/CTS: U2.4 (GPIO2), U6.12 (R1OUT)
/CTSP: J4.8, U6.13 (R1IN)
/MISO1: U1.7 (DO), U2.26 (GPIO20)
/MISO2: U2.16 (GPIO12), U3.7 (DO)
/MOSI1: U1.3 (DI), U2.25 (GPIO19)
/MOSI2: U2.15 (GPIO11), U3.3 (DI)
/NOISE1: C9.1, R19.1, R20.2, U2.31 (GPIO26_ADC0)
/NOISE2: C10.1, R22.2, R23.1, U2.32 (GPIO27_ADC1)
/PICTURE: R3.1, U2.22 (GPIO17)
/PS2CLK: D1.2 (A), R8.1, U2.7 (GPIO5)
/PS2DATA: D2.2 (A), R9.1, U2.6 (GPIO4)
/RTS: U2.5 (GPIO3), U6.11 (T1IN)
/RTSP: J4.7, U6.14 (T1OUT)
/SCK1: U1.5 (SCLK), U2.24 (GPIO18)
/SCK2: U2.14 (GPIO10), U3.5 (SCLK)
/UARTRX: J3.3, U2.2 (GPIO1), U6.9 (R2OUT)
/UARTRXP: J4.2, U6.8 (R2IN)
/UARTTX: J3.2, U2.1 (GPIO0), U6.10 (T2IN)
/UARTTXP: J4.3, U6.7 (T2OUT)
/VSYNC: R4.1, U2.21 (GPIO16)
GND: C1.2, C2.2, C3.2, C4.2, C5.2, C6.2, C7.2, C8.2, C13.1, C14.2, C15.2, C16.2, H1.1, H2.1, H3.1, H4.1, J1.1 (SHIELD), J2.2, J3.4, J4.5, P1.3, Q1.1 (E), Q2.1 (E), R5.2, R16.2, R18.1, R19.2, R21.1, R23.2, U1.6 (GND), U2.3 (GND), U2.8 (GND), U2.13 (GND), U2.18 (GND), U2.23 (GND), U2.28 (GND), U2.33 (AGND), U2.38 (GND), U3.6 (GND), U4.2 (GND), U5.1 (GND), U6.15 (GND)
unnamed: D3.2 (A), L1.2, Q2.3 (C)
unnamed: C7.1, C8.1, D3.1 (K), Q3.1 (E), Q4.1 (E), R17.1
unnamed: J1.2 (PIN), R3.2, R4.2, R5.1
unnamed: P1.1, R7.2, R9.2
unnamed: P1.5, R6.2, R8.2
unnamed: Q1.2 (B), R16.1, R17.2
unnamed: Q1.3 (C), R12.1, U5.5 (CV)
unnamed: Q2.2 (B), R15.2
unnamed: C9.2, Q3.2 (B), R18.2
unnamed: C10.2, Q4.2 (B), R21.2
unnamed: C1.1, R1.2, U1.4 (VDD)
unnamed: R10.2, U2.37 (3V3_EN)
unnamed: R11.2, U2.30 (RUN)
unnamed: C2.1, R2.2, U3.4 (VDD)
unnamed: C3.1, C15.1, J2.1, U4.1 (VI)
unnamed: R13.1, R14.2, U5.7 (DIS)
unnamed: R15.1, U5.3 (Q)
unnamed: C6.1, R13.2, U5.2 (TR), U5.6 (THR)
unnamed: C12.1, U6.1 (C1+)
unnamed: C12.2, U6.3 (C1-)
unnamed: C11.1, U6.4 (C2+)
unnamed: C11.2, U6.5 (C2-)
unnamed: C14.1, U6.2 (VS+)
unnamed: C13.2, U6.6 (VS-)

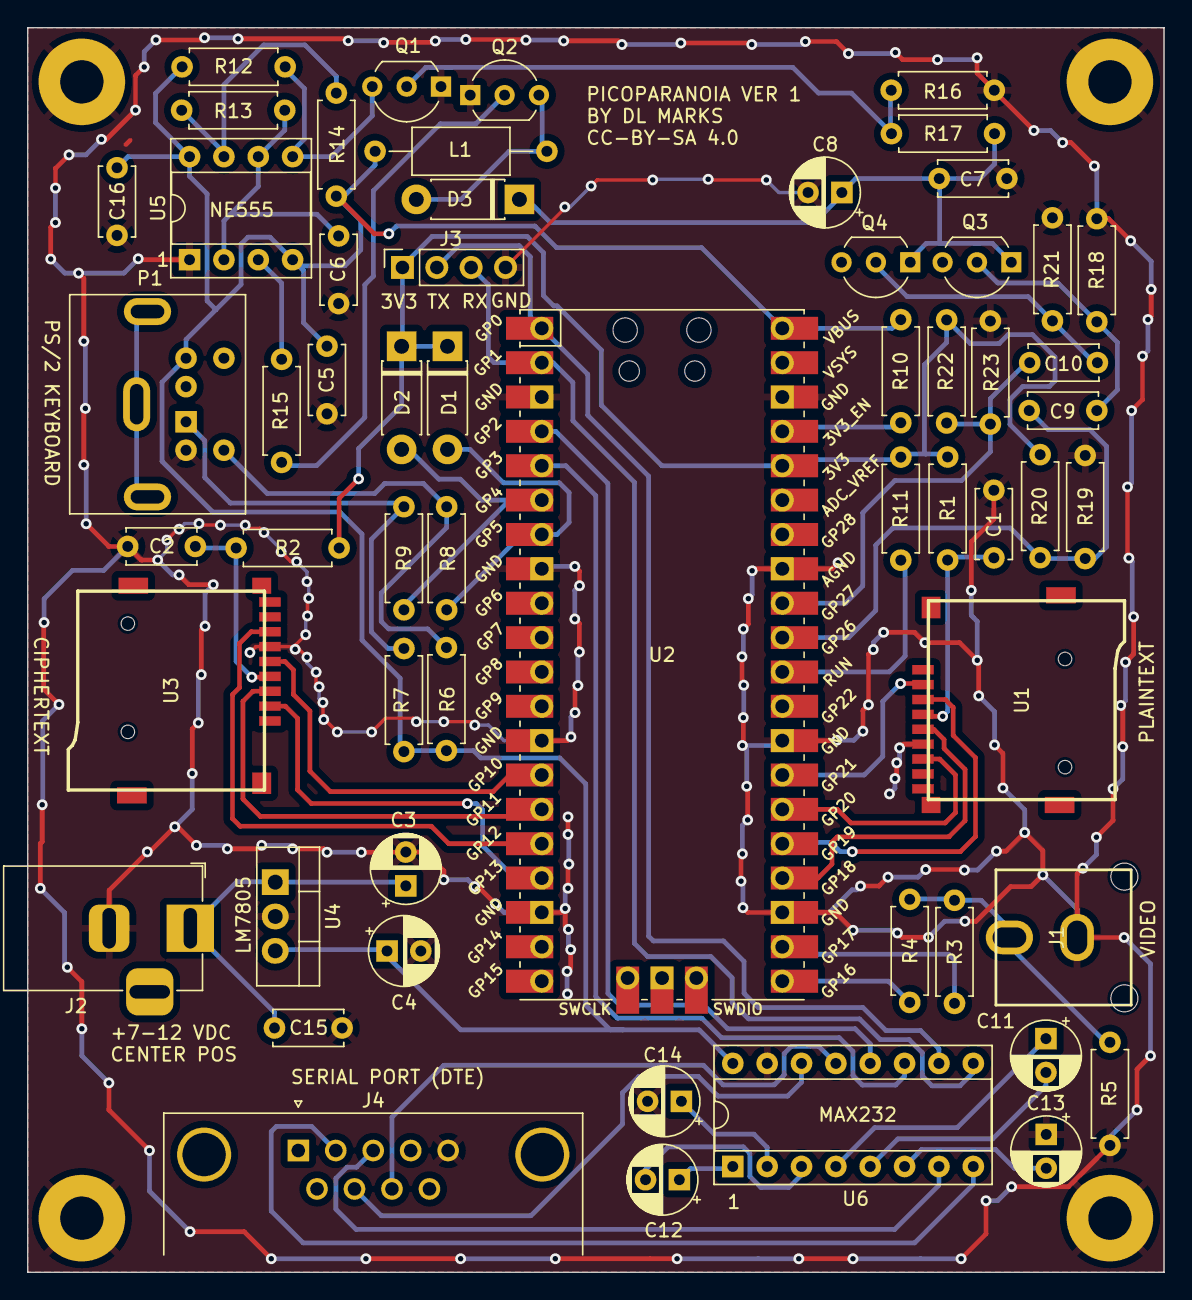
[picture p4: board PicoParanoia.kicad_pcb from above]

Board: 2 copper layers, 84.0 x 92.0 mm, 62 parts (0 on the bottom side), 49 nets.

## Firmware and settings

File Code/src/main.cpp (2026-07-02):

// PicoParanoia — main program.
//
// Boots the console (video + keyboard), runs the vendored crypto KATs and the
// entropy-circuit health check silently, then goes straight into the main
// menu.

#include <stdio.h>
#include <string.h>
#include "pico/stdlib.h"

#include "consoleio.h"
#include "fileop.h"
#include "editor.h"
#include "random.h"
#include "keymanager.h"
#include "fileenc.h"

#include <BLAKE2s.h>
#include <GCM.h>
#include <AES.h>
#include <Curve25519.h>
#include <ChaChaPoly.h>

// ---------------- crypto known-answer self-test ----------------

static void crypto_selftest(int *passed, int *failed) {
    int pass = 0, fail = 0;
    uint8_t out[32];
    static const uint8_t blake_empty[32] = {
        0x69,0x21,0x7a,0x30,0x79,0x90,0x80,0x94,0xe1,0x11,0x21,0xd0,0x42,0x35,0x4a,0x7c,
        0x1f,0x55,0xb6,0x48,0x2c,0xa1,0xa5,0x1e,0x1b,0x25,0x0d,0xfd,0x1e,0xd0,0xee,0xf9 };
    { BLAKE2s b; b.reset(); b.finalize(out, sizeof out);
      (memcmp(out, blake_empty, 32) == 0 ? pass : fail)++; }
    static const uint8_t key[32] = {0}, iv[12] = {0};
    static const uint8_t gcm_tag[16] = {
        0xd0,0xd1,0xc8,0xa7,0x99,0x99,0x6b,0xf0,0x26,0x5b,0x98,0xb5,0xd4,0x8a,0xb9,0x19 };
    { static const uint8_t pt[16] = {0}; uint8_t ct[16], tag[16];
      GCM<AES256> gcm; gcm.setKey(key, 32); gcm.setIV(iv, 12);
      gcm.encrypt(ct, pt, 16); gcm.computeTag(tag, 16);
      (memcmp(tag, gcm_tag, 16) == 0 ? pass : fail)++; }
    // Curve25519 RFC 7748 §5.2 KAT. eval() does not clamp (dh1 normally does),
    // so we clamp the input scalar first. This validates the vendored curve on
    // hardware; keymanager exercises dh1()/dh2() (and thus our RNGClass::rand
    // glue) once it lands.
    static const uint8_t c25519_scalar[32] = {
        0xa5,0x46,0xe3,0x6b,0xf0,0x52,0x7c,0x9d,0x3b,0x16,0x15,0x4b,0x82,0x46,0x5e,0xdd,
        0x62,0x14,0x4c,0x0a,0xc1,0xfc,0x5a,0x18,0x50,0x6a,0x22,0x44,0xba,0x44,0x9a,0xc4 };
    static const uint8_t c25519_u[32] = {
        0xe6,0xdb,0x68,0x67,0x58,0x30,0x30,0xdb,0x35,0x94,0xc1,0xa4,0x24,0xb1,0x5f,0x7c,
        0x72,0x66,0x24,0xec,0x26,0xb3,0x35,0x3b,0x10,0xa9,0x03,0xa6,0xd0,0xab,0x1c,0x4c };
    static const uint8_t c25519_out[32] = {
        0xc3,0xda,0x55,0x37,0x9d,0xe9,0xc6,0x90,0x8e,0x94,0xea,0x4d,0xf2,0x8d,0x08,0x4f,
        0x32,0xec,0xcf,0x03,0x49,0x1c,0x71,0xf7,0x54,0xb4,0x07,0x55,0x77,0xa2,0x85,0x52 };
    { uint8_t s[32], r[32];
      memcpy(s, c25519_scalar, 32);
      s[0] &= 0xF8; s[31] = (s[31] & 0x7F) | 0x40;   // X25519 clamp
      Curve25519::eval(r, s, c25519_u);
      (memcmp(r, c25519_out, 32) == 0 ? pass : fail)++; }
    // ChaCha20-Poly1305 KAT: draft-nir-cfrg-chacha20-poly1305-04 / RFC 8439
    // sec 2.8.2 "Sunscreen" vector, copied verbatim from the vendored
    // library's own TestChaChaPoly.ino (not vendored itself -- just the
    // source of these bytes) so there's no hand-transcription risk. Not
    // wired into symmetric_memcrypt() yet: this only proves the vendored
    // primitive is correct. NOTE for that later step: ChaChaPoly::ivSize()
    // returns 8 (the original 64-bit-nonce variant) by default, NOT 12 --
    // setIV() must be called with an explicit length of 12 (as done here)
    // to get the IETF/RFC 8439 96-bit nonce everything else assumes;
    // trusting cipher.ivSize() the way symmetric_memcrypt() currently does
    // for GCM would silently pick the wrong nonce size.
    static const uint8_t cc_key[32] = {
        0x80,0x81,0x82,0x83,0x84,0x85,0x86,0x87,0x88,0x89,0x8a,0x8b,0x8c,0x8d,0x8e,0x8f,
        0x90,0x91,0x92,0x93,0x94,0x95,0x96,0x97,0x98,0x99,0x9a,0x9b,0x9c,0x9d,0x9e,0x9f };
    static const uint8_t cc_iv[12] = {
        0x07,0x00,0x00,0x00,0x40,0x41,0x42,0x43,0x44,0x45,0x46,0x47 };
    static const uint8_t cc_aad[12] = {
        0x50,0x51,0x52,0x53,0xc0,0xc1,0xc2,0xc3,0xc4,0xc5,0xc6,0xc7 };
    static const uint8_t cc_pt[114] = {
        0x4c,0x61,0x64,0x69,0x65,0x73,0x20,0x61,0x6e,0x64,0x20,0x47,0x65,0x6e,0x74,0x6c,
        0x65,0x6d,0x65,0x6e,0x20,0x6f,0x66,0x20,0x74,0x68,0x65,0x20,0x63,0x6c,0x61,0x73,
        0x73,0x20,0x6f,0x66,0x20,0x27,0x39,0x39,0x3a,0x20,0x49,0x66,0x20,0x49,0x20,0x63,
        0x6f,0x75,0x6c,0x64,0x20,0x6f,0x66,0x66,0x65,0x72,0x20,0x79,0x6f,0x75,0x20,0x6f,
        0x6e,0x6c,0x79,0x20,0x6f,0x6e,0x65,0x20,0x74,0x69,0x70,0x20,0x66,0x6f,0x72,0x20,
        0x74,0x68,0x65,0x20,0x66,0x75,0x74,0x75,0x72,0x65,0x2c,0x20,0x73,0x75,0x6e,0x73,
        0x63,0x72,0x65,0x65,0x6e,0x20,0x77,0x6f,0x75,0x6c,0x64,0x20,0x62,0x65,0x20,0x69,
        0x74,0x2e };
    static const uint8_t cc_ct[114] = {
        0xd3,0x1a,0x8d,0x34,0x64,0x8e,0x60,0xdb,0x7b,0x86,0xaf,0xbc,0x53,0xef,0x7e,0xc2,
        0xa4,0xad,0xed,0x51,0x29,0x6e,0x08,0xfe,0xa9,0xe2,0xb5,0xa7,0x36,0xee,0x62,0xd6,
        0x3d,0xbe,0xa4,0x5e,0x8c,0xa9,0x67,0x12,0x82,0xfa,0xfb,0x69,0xda,0x92,0x72,0x8b,
        0x1a,0x71,0xde,0x0a,0x9e,0x06,0x0b,0x29,0x05,0xd6,0xa5,0xb6,0x7e,0xcd,0x3b,0x36,
        0x92,0xdd,0xbd,0x7f,0x2d,0x77,0x8b,0x8c,0x98,0x03,0xae,0xe3,0x28,0x09,0x1b,0x58,
        0xfa,0xb3,0x24,0xe4,0xfa,0xd6,0x75,0x94,0x55,0x85,0x80,0x8b,0x48,0x31,0xd7,0xbc,
        0x3f,0xf4,0xde,0xf0,0x8e,0x4b,0x7a,0x9d,0xe5,0x76,0xd2,0x65,0x86,0xce,0xc6,0x4b,
        0x61,0x16 };
    static const uint8_t cc_tag[16] = {
        0x1a,0xe1,0x0b,0x59,0x4f,0x09,0xe2,0x6a,0x7e,0x90,0x2e,0xcb,0xd0,0x60,0x06,0x91 };
    { uint8_t ct[114], tag[16];
      ChaChaPoly cp;
      cp.setKey(cc_key, 32);
      cp.setIV(cc_iv, 12);
      cp.addAuthData(cc_aad, 12);
      cp.encrypt(ct, cc_pt, 114);
      cp.computeTag(tag, 16);
      (memcmp(ct, cc_ct, 114) == 0 && memcmp(tag, cc_tag, 16) == 0 ? pass : fail)++; }
    { uint8_t pt[114];
      ChaChaPoly cp;
      cp.setKey(cc_key, 32);
      cp.setIV(cc_iv, 12);
      cp.addAuthData(cc_aad, 12);
      cp.decrypt(pt, cc_ct, 114);
      (memcmp(pt, cc_pt, 114) == 0 && cp.checkTag(cc_tag, 16) ? pass : fail)++; }
    printf("crypto self-test: %d passed, %d failed\n", pass, fail);
    if (passed) *passed = pass;
    if (failed) *failed = fail;
}

// Main menu.
static const char mainmenu[] =
    "\r\n\r\nM - Mount Drives\r\n\
T - Text Editor\r\n\
N - New File\r\n\
V - View File\r\n\
X - Delete File\r\n\
E - Encrypt File\r\n\
D - Decrypt File\r\n\
R - Randomness Test\r\n\
Z - Show Raw Noise\r\n\
C - Capture Entropy to File\r\n\
K - Key Manager\r\n\
"
"\r\n\r\nOption: ";
static const char mainmenuoptions[] = "MTNVXEDRZCK";

int main(void) {
    // console_init() brings up video (sets sysclk 126 MHz) and the keyboard;
    // do it before stdio_init_all().
    console_init();

    stdio_init_all();
    crypto_selftest(NULL, NULL);   // logged via printf only; no TV display

    random_initialize();
    if (!random_circuit_check()) {
        console_clrscr();
        console_highvideo();
        console_puts("ENTROPY CIRCUIT ERROR\r\n");
        console_lowvideo();
        console_puts("Noise source failed its health check.\r\n");
        console_puts("Keys/nonces may not be safe to\r\ngenerate until this is fixed.\r\n");
        console_press_space();
    }

    keymanager_initialize();
    file_mount_volume(0);   // mount both cards (fileop's fs0/fs1)

    for (;;) {
        console_clrscr();
        console_highvideo();
        console_puts("PicoParanoia");
        console_lowvideo();
        console_puts(" by D. Marks\r\n");
        console_puts("Ciphertext card ");
        console_highvideo();
        console_puts(fs0_mounted ? "present" : "absent");
        console_lowvideo();
        console_puts("\r\nPlaintext card ");
        console_highvideo();
        console_puts(fs1_mounted ? "present" : "absent");
        console_lowvideo();
        console_puts("\r\nPriv key: ");
        console_highvideo();
        keymanager_display_key(-1, &current_key_private);
        console_lowvideo();
        console_puts("\r\nPub key:  ");
        console_highvideo();
        keymanager_display_key(-1, &current_key_public);
        console_lowvideo();

        int option = console_selectmenu(mainmenu, mainmenuoptions);
        switch (option) {
            case 'M': file_mount_volume(0); break;
            case 'T': file_edit();          break;
            case 'N': file_new();           break;
            case 'V': file_view();          break;
            case 'X': file_delete();        break;
            case 'E': fileenc_encrypt();    break;
            case 'D': fileenc_decrypt();    break;
            case 'R': randomness_test();    break;
            case 'Z': randomness_show();    break;
            case 'C': randomness_capture_to_file(); break;
            case 'K': keymanager();         break;
        }
    }
}

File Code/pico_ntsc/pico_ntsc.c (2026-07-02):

// pico_ntsc — composite scanout engine + text framebuffer.
//
// Monochrome NTSC via one PIO SM (2 bits/sample: GPIO16 sync, GPIO17 luma) fed
// by a self-reloading DMA loop over a precomputed frame. Glyphs are blitted into
// the frame's active region; the cursor is XOR-rendered from a repeating timer.
// See pico_ntsc.h and PORTING.md §1.5.
//
// The system clock is chosen so the horizontal line rate is EXACT (not an
// approximation): sysclk 126 MHz (= 12 MHz * 126 / (6*2)), clkdiv 7 -> sample
// clock exactly 18 MHz. 18 MHz / 1144 = 4.5 MHz / 286 = 15734.2657 Hz, the exact
// NTSC line rate; 262 lines -> 60.06 Hz. (PAL reuses the same 126 MHz / 18 MHz
// with 1152 samples/line -> exactly 15625 Hz and 312 lines -- a two-constant
// swap.) The active window is a NARROW ~35.6 us (640 px) with a fat ~9.8 us back
// porch, matching the proven STM32 ParanoiaBox generator so it sits inside TV
// overscan.
//
// 1144 is not a multiple of 16, so scanlines are not word-aligned; we index the
// framebuffer by ABSOLUTE sample number. The frame total (1144*262 = 299728
// samples = 18733 words) *is* word-aligned, which is all the looping DMA needs.

#include "pico_ntsc.h"

#include <string.h>
#include "pico/stdlib.h"
#include "hardware/clocks.h"
#include "hardware/pio.h"
#include "hardware/dma.h"
#include "hardware/sync.h"
#include "ntsc.pio.h"

#define NTSC_PIN_SYNC 16   // out bit 0
#define NTSC_PIN_LUMA 17   // out bit 1

// --- horizontal timing, in 18 MHz samples (1 sample ~= 55.6 ns) ---
#define SAMPLE_CLKDIV 7                    // 126 MHz / 7 = 18 MHz
#define LINE_SAMPLES  1144                 // 63.556 us -> 15734 Hz
#define HSYNC         85                   // 4.7 us leading sync tip
#define ACTIVE_START  300                  // active begins ~16.7 us into the line (horizontal position; tunable)
#define ACTIVE        640                  // 80*8 px (35.6 us) -- narrow, inside overscan
#define VS_TAIL       85                   // vertical-sync line is sync-low except this 4.7 us tail

// --- vertical structure (progressive; two line types only) ---
#define V_LINES       262
#define V_SYNC_LINES  3                    // vertical-blank (sync-low) lines; tunable
#define ACTIVE_LINE0  30                   // first active text scanline (matches STM32 NTSC_VTOP)
#define CELL_H        8
#define CURSOR_BLINK_MS 300

#define FRAME_SAMPLES (LINE_SAMPLES * V_LINES)   // 299728
#define FRAME_WORDS   (FRAME_SAMPLES / 16)       // 18733 (frame total is word-aligned)

// --- state ---
static uint32_t frame[FRAME_WORDS];
static const uint32_t *const frame_src = frame;
static const uint8_t (*cur_font)[8] = pico_ntsc_font_unscii8;
static pico_ntsc_mode_t cur_mode = PICO_NTSC_MODE_80;
static int  cur_cols = 80;
static int  cur_row, cur_col;
static bool cur_visible, cur_shown;
static repeating_timer_t blink_timer;

// One 2-bit sample at ABSOLUTE index i: bit0 = sync (0 = sync tip), bit1 = luma.
static inline void put(int i, int sync, int luma) {
    uint32_t bits = (sync ? 1u : 0u) | (luma ? 2u : 0u);
    int w = i >> 4, shift = (i & 15) * 2;
    frame[w] = (frame[w] & ~(3u << shift)) | (bits << shift);
}
static inline void luma_set(int i, int v) {
    int w = i >> 4, b = (i & 15) * 2 + 1;
    if (v) frame[w] |= (1u << b); else frame[w] &= ~(1u << b);
}
static inline void luma_xor(int i) {
    int w = i >> 4, b = (i & 15) * 2 + 1;
    frame[w] ^= (1u << b);
}

// Sample index of column x within scanline L.
static inline int sample_at(int line, int x) { return line * LINE_SAMPLES + x; }

static void build_frame(void) {
    for (int L = 0; L < V_LINES; L++) {
        int base = L * LINE_SAMPLES;
        if (L < V_SYNC_LINES) {
            // Vertical-blank line: sync low for most of the line, released at the tail.
            for (int i = 0; i < LINE_SAMPLES; i++)
                put(base + i, (i < LINE_SAMPLES - VS_TAIL) ? 0 : 1, 0);
        } else {
            // Standard line: leading HSYNC tip, then blanking (black).
            for (int i = 0; i < LINE_SAMPLES; i++) put(base + i, 1, 0);
            for (int i = 0; i < HSYNC; i++)        put(base + i, 0, 0);
        }
    }
}

// --- blitting ---

void pico_ntsc_put_cell(int row, int col, uint8_t cell) {
    if (row < 0 || row >= PICO_NTSC_ROWS || col < 0 || col >= cur_cols) return;
    int scale = (cur_mode == PICO_NTSC_MODE_40) ? 2 : 1;
    int x0 = ACTIVE_START + col * 8 * scale;
    uint8_t g = cell & 0x7F;
    int reverse = cell & 0x80;

    uint32_t save = save_and_disable_interrupts();
    if (cur_shown && row == cur_row && col == cur_col) cur_shown = false;  // don't fight the cursor
    for (int gr = 0; gr < CELL_H; gr++) {
        int line = ACTIVE_LINE0 + row * CELL_H + gr;
        uint8_t bits = cur_font[g][gr];
        for (int gc = 0; gc < 8; gc++) {
            int lum = ((bits & (0x80 >> gc)) ? 1 : 0) ^ (reverse ? 1 : 0);
            int s = sample_at(line, x0 + gc * scale);
            luma_set(s, lum);
            if (scale == 2) luma_set(s + 1, lum);
        }
    }
    restore_interrupts(save);
}

void pico_ntsc_put_text(int row, int col, const char *s, bool reverse) {
    while (*s && col < cur_cols)
        pico_ntsc_put_cell(row, col++, (uint8_t)*s++ | (reverse ? 0x80 : 0));
}

// Fill absolute sample range [S, E) to solid black/white. Assumes the whole
// range lies in the "sync released" active window, which holds for every
// caller here since ACTIVE_START is well past HSYNC. Whole 32-bit words
// inside the range are stored directly, with no read-modify-write -- both
// the sync bit (always 1/released) and the luma bit (the fill value) are
// known constants for every sample in an interior word. Only the (at most
// 15-sample) partial words at each end need masking.
//
// This is what actually matters for flicker: the naive per-sample loop this
// replaces called the (never-inlined-in-practice) luma_set() once per 2-bit
// sample, ~30 cycles each -- a full-screen clear (128,000 samples) cost
// ~30ms, comparable to TWO 16.67ms frame periods, so the DMA scanned clean
// across the whole screen roughly twice while the clear was still in
// progress: guaranteed visible tearing, regardless of how the fill was
// triggered. Word stores cost ~1-2 cycles per 16 samples.
static inline void fill_span(int S, int E, bool reverse) {
    if (S >= E) return;
    uint32_t fillword = reverse ? 0xFFFFFFFFu : 0x55555555u;  // sync=1, luma=1|0, x16
    int w0 = S >> 4, b0 = S & 15;
    int w1 = E >> 4, b1 = E & 15;

    if (w0 == w1) {
        uint32_t mask = ((1u << ((b1 - b0) * 2)) - 1u) << (b0 * 2);
        frame[w0] = (frame[w0] & ~mask) | (fillword & mask);
        return;
    }
    if (b0 != 0) {
        uint32_t mask = 0xFFFFFFFFu << (b0 * 2);
        frame[w0] = (frame[w0] & ~mask) | (fillword & mask);
        w0++;
    }
    for (int w = w0; w < w1; w++) frame[w] = fillword;
    if (b1 != 0) {
        uint32_t mask = (1u << (b1 * 2)) - 1u;
        frame[w1] = (frame[w1] & ~mask) | (fillword & mask);
    }
}
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

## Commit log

2025-09-06 JLCPCB order
    [PicoParanoia-B_Cu.gbr, PicoParanoia-B_Mask.gbr, PicoParanoia-B_Paste.gbr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]
2025-09-16 Swapped cipher and plaintext cards
    [PicoParanoia-B_Cu.gbr, PicoParanoia-B_Mask.gbr, PicoParanoia-B_Paste.gbr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]
2026-06-30 Add Pico SDK and buildable firmware skeleton
    Vendor the Raspberry Pi Pico SDK 2.2.0 as a submodule and add a
    CMake-based project in Code/ that builds against it. Includes a
    blink + USB-serial starter (main.c) to verify the toolchain.
2026-06-30 Add porting plan (STM32 ParanoiaBox -> RP2040 Pico)
    Document the hardware differences, RP2040 pin map, two-bus SD card
    security design, text-cell NTSC video approach, and a module-by-module
    port strategy with a bottom-up bring-up order.
2026-06-30 Plan USB-host keyboard support and stdio migration
    Add USB keyboard (RP2040 as USB host via TinyUSB) alongside PS/2, both
    feeding one key-event queue. Document the single-USB-controller
    device-vs-host tradeoff: USB-CDC debug stdio is bring-up scaffolding that
    moves to uart0 (or is compiled out) once USB flips to host mode. Update
    the module table and add a step 9 to the bring-up order.
2026-06-30 Expand porting plan: auditability, USB-optional, deps, RNG
    - Add §0 design principles (auditability-first; standalone reusable
    pico_ntsc video library).
    - Settle the video architecture in §1.5 (2-resistor mono composite,
    240p, lockstep PIO SMs + ping-pong DMA, 1bpp framebuffer, 40/80-col).
    - Make USB compile-time optional and OFF by default; default debug on
    uart0 (§1.7).
    - Pin/record dependencies (§2.3): FatFs R0.16, Arduino Crypto lib subset
    @37a76b8; repo/library layout (§2.2).
    - Note the ~100mV noise source: only low ADC LSBs are random, so credit
    conservatively and oversample very generously, with a stuck-source
    health check (§1.3.1).
    - Decide the RNG construction: dir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
2026-06-30 Bring-up step 1: copy-to-RAM skeleton + crypto self-test
    Vendor a pinned, minimal subset of the Arduino Cryptography Library
    (commit 37a76b8) into third_party/crypto — GCM/AES256/CTR/BLAKE2s and
    their dependencies, verbatim, with PROVENANCE.md + LICENSE. Curve25519
    and the RNG/ChaCha/NoiseSource code are deliberately excluded (deferred
    to step 5 / replaced by direct BLAKE2s extraction).
    Restructure the build: src/main.cpp self-tests AES-256-GCM and BLAKE2s
    against known-answer vectors over uart0, copy_to_ram binary type (runs
    entirely from SRAM), USB stdio off. ~47 KB RAM used, ~217 KB free.
    [main.cpp]
2026-06-30 Use USB-CDC stdio for bring-up testing
    Temporary: switch the debug console from uart0 to USB-CDC so the crypto
    self-test can be read over the USB cable with no UART adapter. Native USB
    stays in device mode (host support is deferred). The §1.7 default
    (uart0 + USB off) is restored before USB-host support lands.
2026-06-30 pico_ntsc: scaffold library + public-domain font tables
    Start step 2 (video). Add the standalone pico_ntsc static library and
    two readability-tuned 8x8 font tables generated from public-domain
    sources: unscii-8 (regular, for 80-col) and unscii-8-thin (40-col),
    with 0x00-0x1F spliced from the old raster88_font. Single-byte cell
    model (glyph = cell & 0x7F, bit7 = reverse); global font choice.
    Builds clean; PIO/DMA scanout engine to follow.
2026-06-30 pico_ntsc: NTSC 240p test pattern (first light)
    Add the PIO/DMA composite scanout engine. One PIO SM emits 2 bits/sample
    (GPIO16 sync, GPIO17 luma) at 12.6 MHz (sysclk 126 MHz / 10); 800
    samples/line = 15750 Hz, 262 lines = 60.1 Hz. A self-reloading DMA loop
    streams a precomputed full-frame buffer (equalizing / serration / blank /
    active line templates), so the pattern is fully static with no CPU or
    core1. Test pattern: 16px vertical bars with a white border, in a 200-line
    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
2026-06-30 pico_ntsc: text framebuffer, blitter, cursor, 40/80-col
    Turn the static test frame into a text display. Glyph blitter writes into
    the active region (blit-on-write, core0); public API: pico_ntsc_init /
    put_cell / put_text / clear / set_mode / set_font / set_cursor. The cursor
    (position, visibility, blink) is owned by the library and XOR-rendered
    from a repeating hardware timer (no core1). 80-col and 40-col (double-width
    pixels). main() runs the crypto KAT once, then cycles a demo through both
    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
2026-06-30 pico_ntsc: progressive 240p vsync; center active window
    The interlace-style equalizing + half-line serration pulses produced
    extra mid-line sync edges that disturbed the TV's horizontal oscillator
    (wobbly top lines) and threw off vertical lock (picture floated down and
    off the bottom). Replace with a clean progressive vsync: 3 broad sync
    lines with a single end-of-line serration, so there is exactly one
    horizontal reference per line. Re-center the 200-line active window
    (ACTIVE_LINE0 20 -> 31, equal 31-line top/bottom margins).
    [pico_ntsc.c]
2026-07-01 pico_ntsc: working text video — exact NTSC timing, correct H geometry
    Rock-steady text confirmed on hardware. The first-light 12.6 MHz pixel
    clock made the active region 80% of the line, so it overscanned off the
    screen edges and crowded the sync. Match the proven STM32 generator
    instead:
    - sysclk 126 MHz, clkdiv 7 -> sample clock exactly 18 MHz.
    - 1144 samples/line = 4.5 MHz/286 = 15734.27 Hz (exact NTSC), 262 lines,
    60.05 Hz. (PAL: same clock, 1152 samples -> exactly 15625 Hz.)
    - Narrow ~35.6 us active (56% of line) + fat ~9.8 us back porch, inside
    overscan. ACTIVE_START / ACTIVE_LINE0 are the H/V position knobs.
    - 1144 is not a multiple of 16, so index the framebuffer by absolute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
    [main.cpp, pico_ntsc.c]
2026-07-01 Console shim + PS/2 keyboard (both confirmed on hardware)
    Add the text console on top of pico_ntsc:
    - TNTSCAnsi: reuse the ParanoiaBox VT100 emulator verbatim, adding one
    optional per-cell hook. VS_PUT writes the char buffer and calls
    TNTSCANSI_CELL_CHANGED (no-op by default, so the file stays a standalone
    emulator). PicoParanoia's tntscansi_hook.h maps it to pico_ntsc_put_cell,
    so each changed cell is blitted directly -- no diff/re-render.
    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
2026-07-01 SD-over-SPI + FatFs R0.16: two independent card buses
    Vendor FatFs R0.16 (portable core: ff.c, ffunicode.c, ffsystem.c) with
    ffconf.h configured for two volumes, LFN, and mkfs; the sample diskio.c
    is not vendored. Provide the SD-over-SPI disk driver in src/sd_spi.c —
    ChaN's reference protocol logic with the byte exchange, chip select, and
    clock parameterized by the global `curdrv`, which now picks BOTH the SPI
    peripheral and its CS so the two cards live on separate buses (spi1 =
    ciphertext, spi0 = plaintext) and cannot snoop each other.
    Confirmed on hardware: both cards initialize, read, and mount. (An early
    failure was a supply-isolation wiring mistake that sagged Vcc during the
    current-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
    [main.cpp, sd_spi.c]
2026-07-01 File layer: fileop (browse/view/delete) + editor + base64
    Port the ParanoiaBox file layer onto the two-card FatFs backend:
    - editor.c / editor.h: the EE-derived VT100 text editor, verbatim. Its
    only dependency is consoleio (getch/putch/gotoxy/clreol + myltoa/
    mystrtol/MY_ITOASIZE), all already provided by the ported console.
    - fileop.cpp / fileop.h: file select/view/delete + new/edit, plus the
    base64 block armor (file_write_block/read_block) used later by fileenc.
    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
2026-07-01 RNG: direct BLAKE2s extraction from RP2040 ADC noise sources
    Rewrite (not port) of the ParanoiaBox RNG for the RP2040. The STM32 build
    fed a transistor noise source into the Arduino crypto library's ChaCha
    CSPRNG; PicoParanoia instead does direct extraction — gather many raw ADC
    samples and compress them with BLAKE2s — dropping the CSPRNG, ChaCha, and
    NoiseSource entirely to keep the entropy TCB small and auditable. This is
    the approach the STM32 source sketched in a commented-out block but never
    shipped.
    Hardware: two analog noise sources on GPIO26 (ADC0) and GPIO27 (ADC1).
    The physical noise is only ~100 mV, so real randomness lives in the low
    ADC bits; we keep the low byte of each 12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
    [main.cpp, random.cpp]
2026-07-01 RNG test: show histogram max-min spread + total/spread ratio
    Add a uniformity readout to the randomness_test histogram screen: the
    spread between the most- and least-populated bins, and total/spread.
    For a flat distribution bin counts scatter with std dev ~sqrt(N/32), so
    spread grows like sqrt(N) while total grows like N; their ratio should
    climb as sqrt(N) as the test runs. A ratio that stalls (spread growing
    like N) flags a biased source.
    [random.cpp]
2026-07-01 RNG: SP 800-90B RCT+APT health tests + raw capture-to-file
    Add the two NIST SP 800-90B continuous health tests to the raw sample
    path, run per channel on the low-byte stream:
    - Repetition Count Test (RCT): flags a value stuck for too long in a row.
    - Adaptive Proportion Test (APT): non-overlapping 512-sample windows, flags
    a value that dominates a window.
    Cutoffs are for alpha = 2^-20 and an assumed per-sample min-entropy H = 2
    bits (RCT=11, APT=177), computed exactly from the binomial (table in the
    source). H=2 is deliberately conservative: a healthy source spread over
    ~120 low-byte values has an expected APT count ~5, far under 177, so false
    alarms are negligible, while the tests now c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
    [main.cpp, random.cpp]
2026-07-01 flashstruct: RP2040 flash block store + editor buffer to 32K
    Reimplement the ParanoiaBox flashstruct contract for the RP2040. The STM32
    version drove the flash controller directly (half-word program, 1 KB page
    erase); the RP2040 has XIP-mapped flash with 4 KB erase sectors and 256-byte
    program pages. Same interface (read/writeflashstruct serialize a set of
    variable-length blocks); mechanics rewritten:
    - readflashstruct: ordinary loads from the XIP window.
    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
2026-07-01 Crypto core: Curve25519/ECDH, cryptotool helpers, size-optimized build
    Vendor Curve25519 + BigNumberUtil + RNG.h from the pinned arduinolibs commit
    (37a76b8), byte-for-byte verbatim (sha256-verified against upstream). No edits
    to the crypto library.
    ECDH entropy without the Arduino RNG: Curve25519.cpp's dh1() (used by
    keymanager for keygen) calls RNG.rand(). Rather than patch the library, we
    don't compile RNG.cpp and provide our own RNGClass::rand() in
    src/arduino_rng_glue.cpp, routing to randomness_get_whitened_bits() — direct
    ADC-noise + BLAKE2s extraction with the SP 800-90B health checks. So dh1()
    keeps its audited clamping/weak-point logic but draws entropy from our source,
    and the C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
    [cryptotool.h, main.cpp]
2026-07-01 Show crypto self-test (incl. Curve25519 KAT) on the boot screen
    crypto_selftest() now returns pass/fail counts; the boot screen prints them
    on the TV ("Crypto self-test (BLAKE2s/GCM/Curve25519): 3 passed, 0 failed")
    so the Curve25519 RFC 7748 KAT can be verified on hardware without USB serial.
    [main.cpp]
2026-07-01 keymanager: encrypted key store (ECDH keygen + GCM + flash persistence)
    Port the ParanoiaBox key manager — the module that ties the crypto core
    together. The key table (80 entries: AES/passphrase, ECDH private, ECDH
    public) is AES-256-GCM encrypted under a passphrase-derived hash
    (key_derivation_function over a random salt); salt/iv/tag are stored
    cleartext. Plaintext keys live only in the malloc'd key_storage and are
    zeroized on exit, so with copy-to-RAM they never reach the flash bus.
    This is where the whole stack first runs together on real keys:
    - keymanager_new_private_key -> Curve25519::dh1 -> RNGClass::rand (our glue)
    -> randomness_get_whitened_bits (ADC noise + BLAKE2s + SP 800-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
    [main.cpp]
2026-07-02 Default console to 40x25 with the unscii-8-thin font
    80 columns is hard to read on a composite TV. Switch the console default to
    PICO_NTSC_MODE_40 (double-width 16px cells), which also selects the crisper
    unscii-8-thin glyphs. 40 columns is ParanoiaBox's native UI width anyway (the
    file viewer uses 38 cols, key/file menus fit ~40), so the ported screens lay
    out correctly.
    Also reflow the boot/menu text that was written for 80 cols so it no longer
    wraps at 40: the crypto self-test line, the SD probe (two lines per card),
    and shorter Priv/Pub key labels in the main banner.
    [main.cpp]
2026-07-02 Fix key-export HardFault: missing return in fileblockencode_writedata
    keymanager_export_public_key crashed on real hardware. Root cause:
    fileblockencode_writedata (src/fileop.cpp) is declared int but had no
    return statement — undefined behavior in the original ParanoiaBox source
    that happened to be harmless on the STM32/M3 toolchain. On the RP2040
    (Cortex-M0+) at -O2/-Os the compiler emits no return epilogue, so
    execution fell through the literal pool into the next linked function
    (fileblockdecode_readdata), which dereferenced a bogus pointer and
    HardFaulted.
    Found via a new HardFault reporter (src/fault.c): overrides the SDK's
    weak isr_hardfault, recovers the exception frame (PC/LR/R0-R3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
2026-07-02 Fix clear-screen flicker: word-batched framebuffer fill, region-clear hook
    Screen clears visibly flashed on the TV. Root cause: clear_region() drove
    the per-cell TNTSCANSI_CELL_CHANGED hook for every cell in the cleared
    span, which blits a full glyph (font lookup + per-pixel loop) even for a
    blank space -- and there's nothing that pauses the PIO+DMA scanout while
    the CPU writes, so the DMA continuously re-reads the same live frame[]
    buffer being mutated. The write duration IS the tear window.
    First pass (this session, prior commit) added a per-cell "direct fill"
    clear_span/clear_cols path to skip glyph rendering, but it still called
    luma_set() once per 2-bit sample -- a real, non-inlined fu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
    [pico_ntsc.c]
2026-07-02 Extract PS/2 keyboard driver into its own library: pico_ps2kbd
    Housekeeping: move ps2_kbd.c/.h out of src/ into pico_ps2kbd/, structured
    as its own standalone CMake target (own CMakeLists.txt, PUBLIC include
    dir), mirroring pico_ntsc exactly. No logic changes -- the scancode table
    and PS/2 frame state machine are untouched, only the file location, the
    public API prefix (ps2_kbd_* -> pico_ps2kbd_*, matching pico_ntsc_*), and
    the doc comments (framed as decoupled/reusable, per PORTING.md §0.B).
    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
2026-07-02 Blend keystroke timing into the RNG as defense in depth
    pico_ps2kbd now mixes a microsecond timestamp into a running accumulator
    once per fully received PS/2 byte (every byte -- modifiers and key-up
    markers included, not just printable output), keyed on the gap BETWEEN
    completed bytes rather than the intra-byte clock edges: those are timed by
    the keyboard's own oscillator and fairly regular, whereas the gap between
    separate keystrokes carries real human-timing jitter. This is deliberately
    cheap ISR-side xorshift mixing, not a real extractor -- it's raw material
    for a caller to fold into a proper hash-based whitener. New public API:
    pico_ps2kbd_entropy_sample() / _entropy_count(), documented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
    [pico_ps2kbd.c, random.cpp]
2026-07-02 fileenc: encrypt/decrypt files between the plaintext and ciphertext cards
    Port the ParanoiaBox encrypt/decrypt flow -- the reason the two SD buses
    are kept isolated in the first place. Ties together everything built this
    project: keymanager_compute_secret (AES key or ECDH shared secret),
    key_derivation_function (per-file salted key derivation), AES-256-GCM
    streaming encrypt/decrypt, and fileop's base64 block armor for the header/
    tag.
    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
2026-07-02 PORTING.md: mark RNG/flash key store/SD cards/file crypto DONE
    Steps 4-7 of the bring-up order are all confirmed working on hardware as
    of this session, most recently fileenc's encrypt/decrypt round-trip
    (both AES/passphrase and ECDH shared-secret paths). Update the roadmap
    with dates and brief hardware-confirmation notes, matching the style
    already used for steps 1-3.
    Step 8 (integrate) is mostly done -- the menu loop wires everything
    together and it's all been exercised on hardware -- but the "default
    shipping config" (USB off, uart0/no debug) swap from the current
    temporary USB-CDC bring-up console is still outstanding; called that out
    explicitly rather than marking the whole step done.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
2026-07-02 Change R1/R2 from 10R to 0R (power supply isolation fix)
    Fixes the marginal SD card init failures traced to Vcc sag during the
    current-hungry card init sequence.
    [PicoParanoia.kicad_sch]
2026-07-02 Generalize AES-specific naming to SYMMETRIC_* (prep for ChaCha20-Poly1305)
    The plan: AES-256-GCM is 6-7 years old as a choice now; ChaCha20-Poly1305
    is a better default and is available in the vendored Arduino Cryptography
    Library. It uses the identical 256-bit key, 96-bit IV, and 128-bit tag, so
    it should be a near drop-in replacement -- confirmed here by reading the
    actual sizes out of the vendored GCM/AES256 classes (ivSize()=12,
    tagSize()=16, AES256::keySize()=32) before renaming anything.
    This commit is pure renaming, no cipher swap yet: every AES_*/aes_*
    identifier that named a *role* (key/IV/tag/padding length, or a generic
    "symmetric key" concept) becomes SYMMETRIC_*, so keymanager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
    [cryptotool.h]
2026-07-02 Vendor ChaCha20-Poly1305 (candidate AES-256-GCM replacement, not wired in)
    Vendor ChaCha.[ch], ChaChaPoly.[ch], Poly1305.[ch] from the pinned
    arduinolibs commit (37a76b8), byte-for-byte verbatim -- sha256-verified
    against two independent fetches before copying in, same rigor as
    Curve25519. Zero new dependencies: every header these files need
    (Cipher.h, AuthenticatedCipher.h, Crypto.h, BigNumberUtil.h, the four
    utility/ headers) was already vendored.
    ChaChaPoly inherits AuthenticatedCipher (same base as GCMCommon) and
    exposes the identical keySize/ivSize/tagSize/setKey/setIV/encrypt/decrypt/
    computeTag/checkTag surface symmetric_memcrypt() already uses -- confirmed
    structurally close to drop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
    [main.cpp]
2026-07-02 Cut over the active symmetric cipher to ChaCha20-Poly1305
    Clean cutover, per explicit decision: GCM<AES256> is replaced by ChaChaPoly
    everywhere it was actually instantiated -- symmetric_memcrypt()
    (cryptotool.cpp, used for the flash key store and each file's header) and
    fileenc.cpp's streaming payload read_cipher/write_cipher. No caller of
    symmetric_memcrypt() changed (that was the point of the prior SYMMETRIC_*
    renaming pass); no struct or on-disk/on-flash layout changed, since both
    ciphers use the same 256-bit key / 96-bit IV / 128-bit tag sizes.
    The IV-length gotcha found while vendoring is handled explicitly: both call
    sites now pass a hardcoded, clearly-commented SYMMETRIC_IV_WIRE_LEN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
    [cryptotool.h]
2026-07-02 PORTING.md: mark the AES-256-GCM -> ChaCha20-Poly1305 cipher swap done
    Add step 7a documenting the three-part swap (SYMMETRIC_* renaming with a
    byte-for-byte-verified recompile, vendor + KAT-validate ChaChaPoly, cut
    over symmetric_memcrypt()/fileenc), the ivSize() gotcha, and the clean-
    cutover behavior (old AES-GCM data correctly rejected, tag check fires
    before the version check). Fix two now-stale mentions: step 5's flash key
    store description and step 7's "AES/passphrase" key-type wording (should
    be "symmetric/passphrase", matching the SYMMETRIC_* rename). Note in the
    §2 module strategy table that ChaCha/ChaChaPoly/Poly1305 were vendored
    later, alongside the original GCM/AES256/CTR/BLAK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
2026-07-02 keymanager: increase KEY_NUMBER 80 -> 320 (4x)
    Deliberate design choice: private keys never leave this device -- there is
    no export path for them, by design -- so the key store has to hold every
    private, public, and symmetric key a user will ever need on it, not just
    a working subset. 80 slots was an STM32-era default, not a considered
    limit for that requirement.
    320 was chosen against the actual constraints, measured rather than
    guessed: with the flash-write RAM fix (prior commit) RAM is no longer
    the binding factor -- even the absolute flash-imposed ceiling (646 keys,
    zero margin) only uses 76% of free heap. Flash is the real limit: the
    reserved 64 KB region minus the self-test's scratch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
2026-07-02 Restore default shipping config: uart0 debug console, USB off
    Implements the PICOPARANOIA_ENABLE_USB_STDIO option PORTING.md §1.7 always
    specified but never wired up -- CMakeLists.txt hardcoded USB-CDC stdio as
    a "temporary bring-up choice" instead. Default is now OFF: uart0 (GPIO0/1)
    is the debug console, and no USB/TinyUSB code links at all (confirmed: 0
    tud_/tusb_ symbols in the default build, versus 28 with the flag on).
    Image is ~13.4 KB smaller with USB-CDC out of the build. Build with
    -DPICOPARANOIA_ENABLE_USB_STDIO=1 to opt back into USB-CDC for bring-up
    debugging on a board without a UART adapter handy -- verified that path
    still builds and links correctly too.
    No C code changes n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
2026-07-02 USB host: add connection-stage diagnostics (hardware detection stalled)
    Hardware test found the keyboard "not detected" with no way to tell why --
    pico_usbhostkbd had zero visible feedback (tuh_hid_mount_cb silently arms
    report reception with no on-screen indication it ever fired), so "no
    characters when typing" was equally consistent with several different
    failure points.
    Add four monotonic counters at successive connection stages: core1_alive
    (tuh_task() loop iterations -- is core1 even running), dev_mounts
    (tuh_mount_cb -- ANY USB device enumerated, before HID class matching),
    hid_mounts (tuh_hid_mount_cb -- enumerated specifically as HID),
    reports (tuh_hid_report_received_cb -- any HID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
    [main.cpp]
2026-07-02 PORTING.md: mark USB-host keyboard done -- confirmed on hardware
    Step 9 (the last item on the original bring-up roadmap) is now hardware-
    verified. First attempt found the keyboard undetected; root cause was a
    real hardware gap traced through the schematic (a stock Pico module's
    VBUS is power-input-only, no path to source power to a downstream USB
    device), not a firmware bug. The connection-stage diagnostics added along
    the way (menu U) confirmed all four stages -- core1 alive, device mount,
    HID mount, report reception -- once external 5V power was supplied, and
    typed characters (letters, backspace, enter, arrows) work correctly at
    the normal console.
    This closes out the original PORTING.md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
2026-07-02 Remove bring-up screen and F/U diagnostic menu options
    Skip the boot-time bring-up screen and go straight to the main menu;
    crypto self-test still runs but only logs via printf, and the entropy
    circuit check still runs but only displays a screen on failure.
    Flash Store Self-Test and USB Keyboard Diag were bring-up/debugging
    aids for features that are now confirmed working on hardware, so drop
    them along with the diagnostic counters in pico_usbhostkbd that only
    existed to feed the USB diag screen.
    [main.cpp]
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

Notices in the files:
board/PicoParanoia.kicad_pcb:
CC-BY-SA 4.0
